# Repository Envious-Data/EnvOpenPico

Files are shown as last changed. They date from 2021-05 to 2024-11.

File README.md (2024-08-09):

# EnvOpenPico
A RP2040 Based family of MCU boards

### Intentions and Info
The intentions of this project were mainly to learn about MCU design and also to make a rpi pico like device using a RP2040 that has some improvements or changes that you'd find useful, so far Ive changed the type-c port and added a reset button as well as replaced the buck boost IC with a linear regulator which doesnt generate the same switching noise which makes it good for audio.

Ive retained the USB TP pads and also TP6 which is bootsel in their original positions.
a couple of the GPIOs cant retain their original function since Im not using a RT6150B-33GQW so GPIO23 has an optional mosfet for a default on LED instead of controlling the mode for the buck-boost IC.

Ive also got nothing connected on GPIO29 where as the pico has a mosfet to prevent leakage current, im not sure what the use of this GPIO is but if its a wanted feature I can try to add it back.

Update: 09th Aug 2024 - Raspberry pi has released the RP235XA and RP235XB, I have started work on making variants of the main Pico board to fit the RP2350 and RP2354.

### Permissions
You have my permission to fork and learn from this design for your own projects including if you wish to sell those on as a product. 

### Important!!
I have only had the EnvOpenPico made so the other variants like the PicoLipo and the EliteMicro2040 I cant fully confirm if the design works but since its all derived from the main project I should hope it all works as intended.

### Notes
- You should be able to order these and have them entirely assembled by other PCBA suppliers if they have stock of all the parts, ive made sure to label everything in the schematic properly.
- Please ensure you pick a compatible flash chip, you may need to modify the connections to the flash chip, its setup for Winbond W25QxxJVxxx.

### Other
If you want to see pictures of the main PCB you can check out the _photos folder

PCBway kindly sponsored a batch of PCBs which you can see pictures of inside the _photos folder.
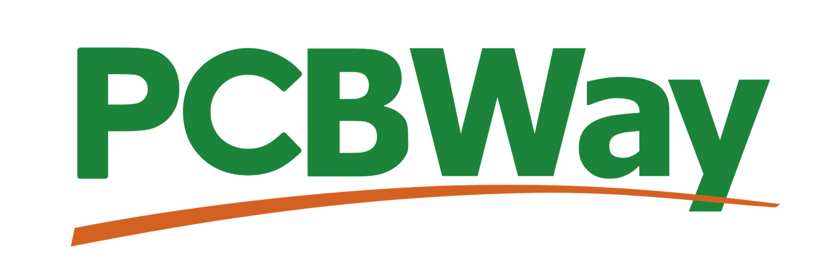
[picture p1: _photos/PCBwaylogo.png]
pcbway logo

http://pcbway.com

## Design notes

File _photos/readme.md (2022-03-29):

PCBWAY Logo

PCBWAY kindly provided some PCBs and components for me, I was also quite impressed at the quality of the PCBs, the castellations are especially good.

https://www.pcbway.com/

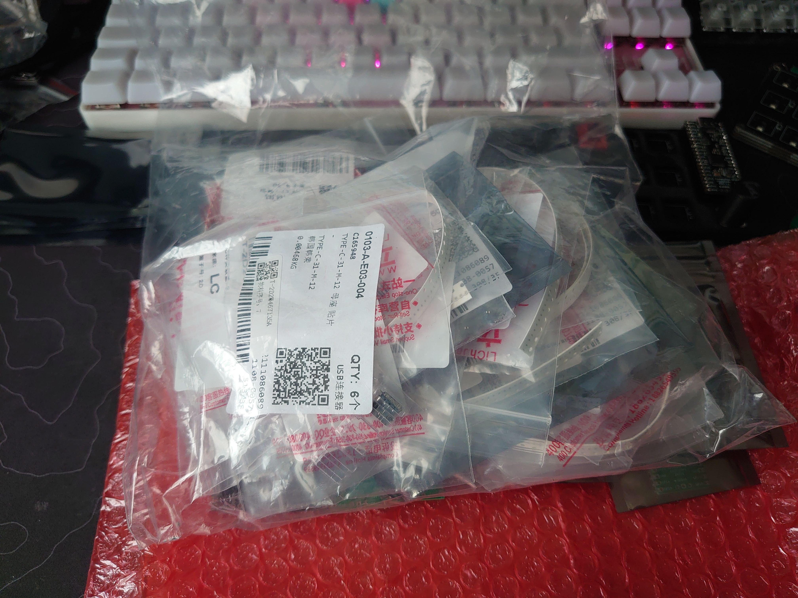
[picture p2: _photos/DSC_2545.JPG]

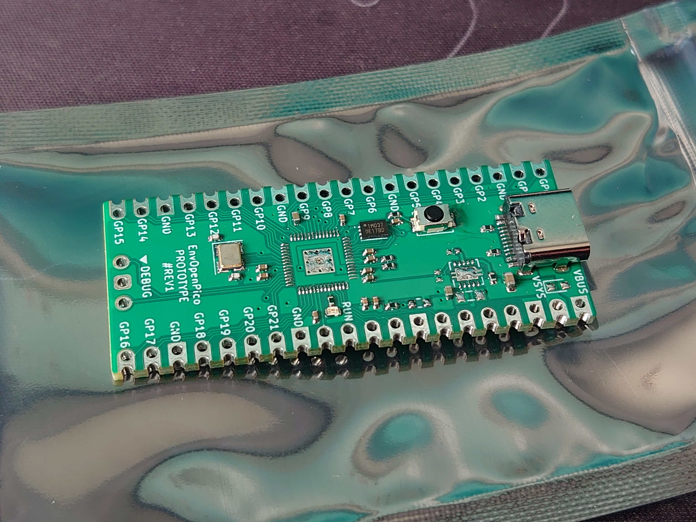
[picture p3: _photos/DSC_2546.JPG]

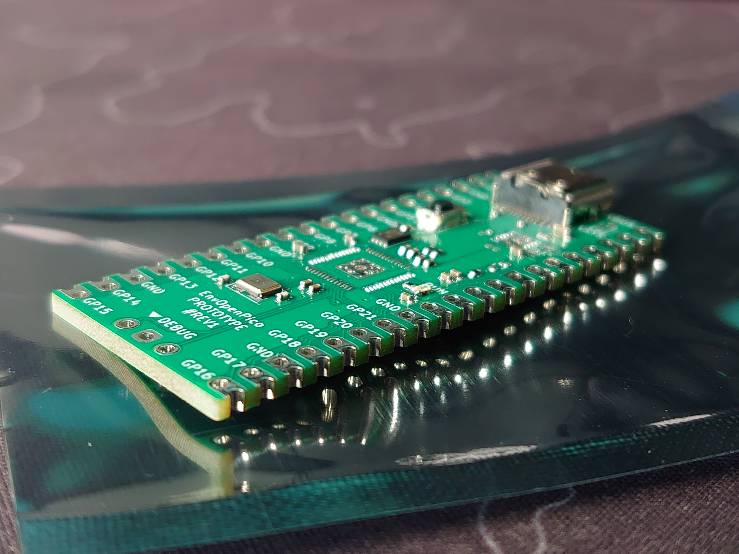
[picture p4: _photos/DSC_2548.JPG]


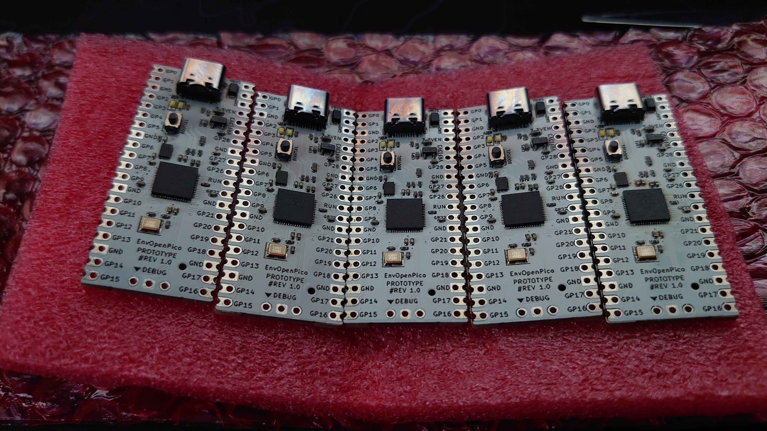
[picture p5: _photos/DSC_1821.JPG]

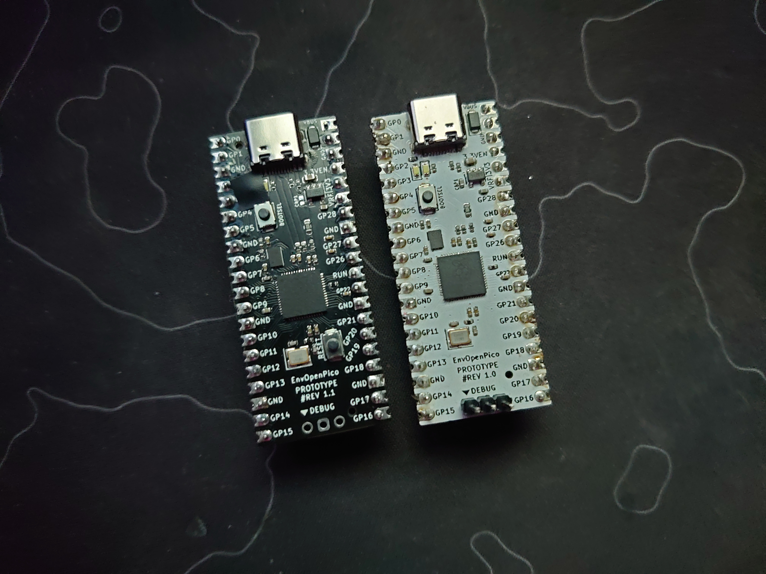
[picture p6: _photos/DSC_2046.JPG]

More PCBs

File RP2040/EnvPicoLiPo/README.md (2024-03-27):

# EnvOpenPico
A Raspberry Pi Pico Clone which also uses the RP2040.

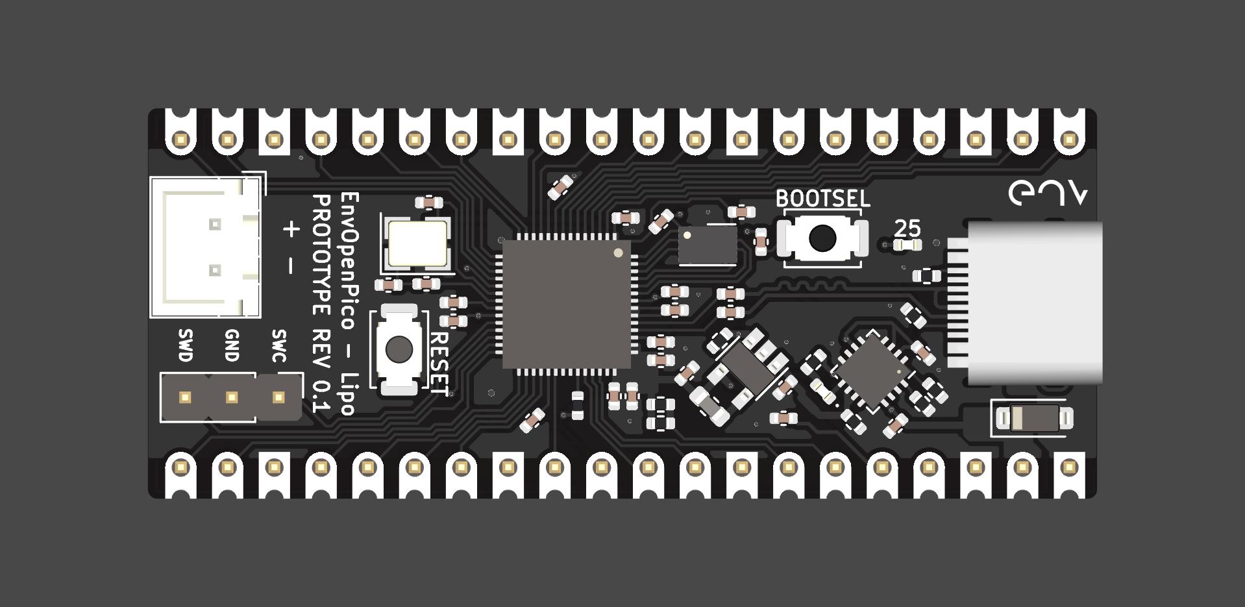
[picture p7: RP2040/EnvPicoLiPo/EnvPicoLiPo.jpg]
Board image


### Info
A pi pico clone with a battery charge and protect IC.

originally this was going to be a version that contains a battery charge IC and a ESP32 wireless slave but I feel like its a bad idea to combine things Ive not worked on before so I scaled back the project to have just a battery PMIC.

### problems
I must point out that alike most things on my github im learning as I go so some pointers on doing things correctly would be apreciated.

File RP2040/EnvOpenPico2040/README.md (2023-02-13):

# EnvOpenPico
A Raspberry Pi Pico Clone which also uses the RP2040.

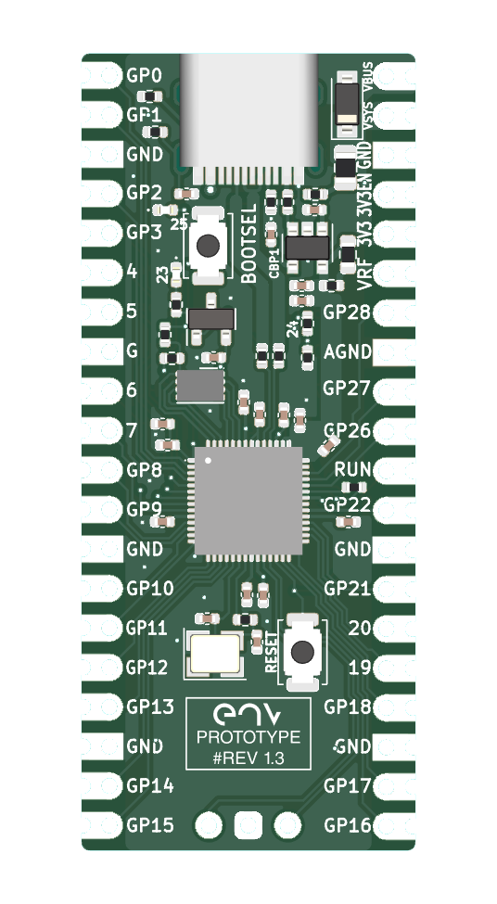
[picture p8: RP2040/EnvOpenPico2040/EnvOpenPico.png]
Board image


### Info
This board is meant to be a mostly drop in replacement for the pico plus and minus some features.

### some notes
I dont update the readme very often so some info here may end up outdated at some point

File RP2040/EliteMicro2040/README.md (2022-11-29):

# EnvOpenPico
A Raspberry Pi RP2040 based board in the shape of an Elite-C.

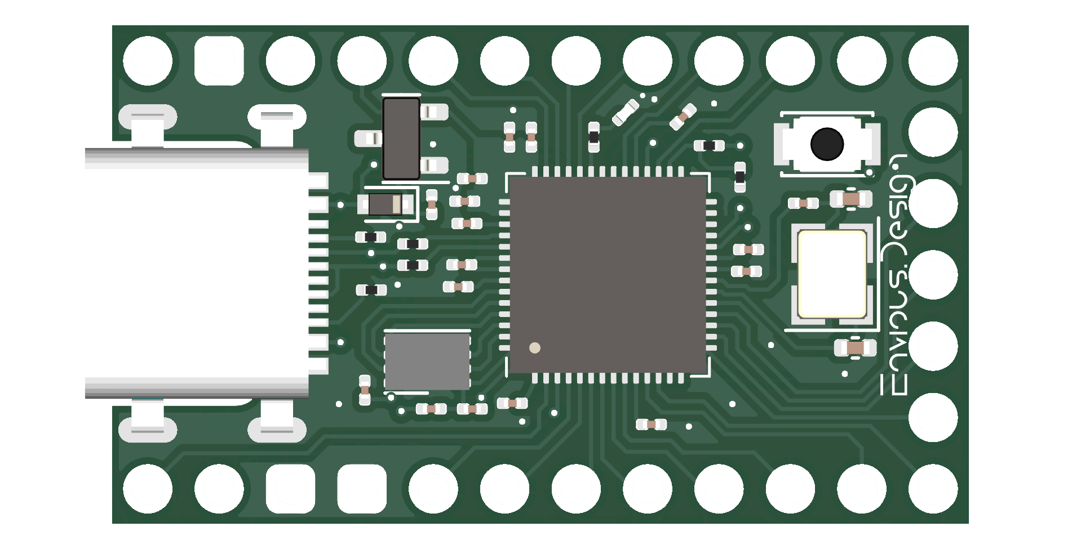
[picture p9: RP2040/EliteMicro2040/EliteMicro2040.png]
Board image


### Info
This board is about 2.5mm shorter than an Elite-C and uses a mid-mount USB C port.

### some notes
I dont update the readme very often so some info here may end up outdated at some point.

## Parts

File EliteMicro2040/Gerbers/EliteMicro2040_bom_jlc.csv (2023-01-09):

Comment | Designator | Footprint | LCSC Part #
1uf 0201 | C1,C3,C4,C10 | C_0201_0603Metric | no_part_number
22pF 0402 | C2 | C_0402_1005Metric | no_part_number
100nf 0201 | C5,C6,C7,C8,C11,C13,C14,C15,C16,C18 | C_0201_0603Metric | no_part_number
22pf 0402 | C19 | C_0402_1005Metric | no_part_number
SOD-523 General | D1 | D_SOD-523 | no_part_number
W25Q16JVUXIQ | FLASH1 | SON-8-1EP_3x2mm_P0.5mm_EP1.4x1.6mm | no_part_number
LED 0201 | GPIO25_LED1 | LED_0201_0603Metric | no_part_number
1K 0201 | GPIO25_RESISTOR1 | R_0201_0603Metric | no_part_number
Button | J1,J2 | SW_SPST_CK_KXT3 | no_part_number
1K 0201 | R1,R7 | C_0201_0603Metric | no_part_number
10K 0201 | R2 | C_0201_0603Metric | no_part_number
27r 0201 | R3,R4 | R_0201_0603Metric | no_part_number
5.1K 0201 | R5,R6 | R_0201_0603Metric | no_part_number
5.6k 0201 | R101 | R_0201_0603Metric | no_part_number
10k 0201 | R102 | R_0201_0603Metric | no_part_number
TestPoint | TP1,TP2,TP101,TP103 | CustomTestPoint | no_part_number
ZL6201A33S3 | U1 | SOT-23 | no_part_number
Elite-C | U2 | Elite-C | no_part_number
RP2040 | U3 | RP2040-QFN-56 | C2040
TYPE-C-31-M-14 | USB1 | USB_C_TYPE-C-31-M-14 | C223907
3225-4P | Y1 | Crystal_SMD_3225-4Pin_3.2x2.5mm | no_part_number

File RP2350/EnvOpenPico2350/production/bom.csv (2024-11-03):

Designator | Footprint | Quantity | Value | LCSC Part #
C1, C17, C4, CBP1 | 0402 | 4 | 10uf 0402
C10, C11, C12, C13, C14, C15, C16, C18, C8 | 0402 | 9 | 100nF 0402
C101 | 0402 | 1 | 0.1uf 0402
C19, C2 | 0402 | 2 | 22pf 0402
C3, C6, C7, C9 | 0402 | 4 | 4.7uF 0402
C5 | 0402 | 1 | 100nf 0402
D1 | D_SOD-123 | 1 | 1N5917W
F1 | 0805 | 1 | 0805L050WR
FB1 | 0402 | 1 | FerriteBead 0402
FLASH1 | Winbond_USON-8-1EP_3x2mm_P0.5mm_EP0.2x1.6mm | 1 | W25Q16JVUXIQ
GP23_LED1 | 0402 | 1 | GP23 LED_0402
GPIO24_RESISTOR1, R1, R11 | 0402 | 3 | 1K 0402
GPIO25_LED1 | 0402 | 1 | LED_0402
GPIO25_RESISTOR1 | 0402 | 1 | 470 0402
J1 | USB_C_Receptacle_HRO_TYPE-C-31-M-12 | 1 | USB_C_Receptacle_USB2.0
J2 | SW_Push_SPST_NO_Alps_SKRK | 1 | TSA343G00-250J2
J3, J4 | PinHeader_1x20_P2.54mm_Vertical | 2 | 2.54mm header 01x20
J5 | PinHeader_1x03_P2.54mm_Vertical | 1 | Conn_01x03_Male
L1 | 0805 | 1 | 3.3uH 0805
NT1 | NetTie-2_SMD_Pad0.5mm | 1 | NetTie_2
Q1 | SOT-23 | 1 | SI2301B
R101 | 0402 | 1 | 5.6K 0402
R102 | 0402 | 1 | 220 0402
R103 | 0402 | 1 | 10K 0402
R2 | 0402 | 1 | 10K 0402
R3, R4 | 0402 | 2 | 27ohm 0402
R5, R6 | 0402 | 2 | 5.1K 0402
R7 | 0402 | 1 | 100K 0402
R8 | 0402 | 1 | 33ohm 0402
RSW1 | SW_Push_SPST_NO_Alps_SKRK | 1 | TSA343G00-250J2
TP1, TP2, TP3 | CustomTestPoint | 3 | TestPoint
U1 | SOT-23-5 | 1 | SOT-23-5 5.5V 3.3V 500mA
U3 | QFN-60-1EP_7x7mm_P0.4mm_EP3.4x3.4mm_ThermalVias | 1 | RP2350A
Y1 | Crystal_SMD_3225-4Pin_3.2x2.5mm | 1 | 3225_4P 12MHz

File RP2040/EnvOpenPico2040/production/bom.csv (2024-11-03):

Designator | Footprint | Quantity | Value | LCSC Part #
C1, C17, C4, CBP1 | 0402 | 4 | 10uf 0402
C10, C102 | 0402 | 2 | 2.2uF 0402
C101 | 0402 | 1 | 0.1uf 0402
C11, C13, C14, C15, C16, C18, C5, C6, C7, C8 | 0402 | 10 | 100nf 0402
C19, C2 | 0402 | 2 | 22pf 0402
C3 | 0402 | 1 | 1uf 0402
D1 | D_SOD-123 | 1 | 1N5817W
F1 | 0805 | 1 | 0805L050WR
FB1 | 0402 | 1 | FerriteBead 0402
FLASH1 | Winbond_USON-8-1EP_3x2mm_P0.5mm_EP0.2x1.6mm | 1 | W25Q16JVUXIQ
GP23_LED1 | 0402 | 1 | GP23 LED_0402
GPIO24_RESISTOR1, R1, R11 | 0402 | 3 | 1K 0402
GPIO25_LED1 | 0402 | 1 | LED_0402
GPIO25_RESISTOR1 | 0402 | 1 | 470 0402
J1 | USB_C_Receptacle_HRO_TYPE-C-31-M-12 | 1 | USB_C_Receptacle_USB2.0
J2 | SW_Push_SPST_NO_Alps_SKRK | 1 | Button
J3, J4 | PinHeader_1x20_P2.54mm_Vertical | 2 | 2.54mm header 01x20
J5 | PinHeader_1x03_P2.54mm_Vertical | 1 | Conn_01x03_Male
NT1 | NetTie-2_SMD_Pad0.5mm | 1 | NetTie_2
Q1 | SOT-23 | 1 | SI2301B
R10 | 0402 | 1 | 1 0402
R101 | 0402 | 1 | 5.6K 0402
R102 | 0402 | 1 | 220 0402
R103 | 0402 | 1 | 10K 0402
R2 | 0402 | 1 | 10K 0402
R3, R4 | 0402 | 2 | 27r 0402 resistor
R5, R6 | 0402 | 2 | 5.1K 0402
R7 | 0402 | 1 | 100K 0402
R9 | 0603 | 1 | 200 0603
RSW1 | SW_Push_SPST_NO_Alps_SKRK | 1 | TSA343G00-250J2
TP1, TP2, TP3 | CustomTestPoint | 3 | TestPoint
U1 | SOT-23-5 | 1 | SOT-23-5 5.5V 3.3V 500mA
U3 | RP2040-QFN-56 | 1 | RP2040 | C2040
Y1 | Crystal_SMD_3225-4Pin_3.2x2.5mm | 1 | 3225_4P 12MHz

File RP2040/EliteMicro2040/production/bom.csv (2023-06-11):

Designator | Footprint | Quantity | Value | LCSC Part #
C1, C10, C3, C4 | 0402 | 4 | 1uf 0402
C11, C13, C14, C15, C18, C5, C6, C7, C8 | 0402 | 9 | 100nf 0402
C19, C2 | 0402 | 2 | 22pf 0402
D1 | D_SOD-523 | 1 | SOD-523 General
FLASH1 | SON-8-1EP_3x2mm_P0.5mm_EP1.4x1.6mm | 1 | W25Q16JVUXIQ
GPIO25_LED1 | 0402 | 1 | LED 0402
GPIO25_RESISTOR1, R1, R7 | 0402 | 3 | 1K 0402
J1, J2 | SW_SPST_CK_KXT3 | 2 | Button
R101 | 0402 | 1 | 5.6k 0402
R102, R2 | 0402 | 2 | 10k 0402
R3, R4 | 0402 | 2 | 27r 0402
R5, R6 | 0402 | 2 | 5.1K 0402
TP1, TP101, TP103, TP2 | CustomTestPoint | 4 | TestPoint
U1 | SOT-23 | 1 | ZL6201A33S3
U2 | Elite-C | 1 | Elite-C
U3 | RP2040-QFN-56 | 1 | RP2040 | C2040
USB2 | HRO-TYPE-C-31-M-12 | 1 | HRO-TYPE-C-31-M-12
Y1 | Crystal_SMD_3225-4Pin_3.2x2.5mm | 1 | 3225-4P 12MHz

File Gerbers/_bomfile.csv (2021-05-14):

Comment | Designator | Footprint | LCSC
10u | C1,C4,C17 | Capacitor_SMD:C_0402_1005Metric
1u | C3,C10 | Capacitor_SMD:C_0402_1005Metric
15p | C2 | Capacitor_SMD:C_0402_1005Metric
100n | C5,C6,C7,C8,C11,C13,C14,C15 | Capacitor_SMD:C_0402_1005Metric
0603 Diode 1N58 | D2 | Diode_SMD:D_0603_1608Metri
LED 0402 YELLOW | D3 | LED_SMD:LED_0402_1005Metric
MountingHole | H1,H2,H3,H4 | MountingHole:MountingHole_2.2mm_M2
B3U-1000P | J2 | Button_Switch_SMD:SW_SPST_B3U-1000P
Conn_02x18_Odd_Even | J3,J4 | Connector_PinHeader_2.54mm:PinHeader_1x20_P2.54mm_Vertical
Conn_01x03_Male | J5 | Connector_PinHeader_2.54mm:PinHeader_1x03_P2.54mm_Vertical
1k | R1 | Capacitor_SMD:C_0402_1005Metric
DNF | R2 | Capacitor_SMD:C_0402_1005Metric
27 0402 Resistor | R3,R4 | Capacitor_SMD:C_0402_1005Metric
5.1K | R5,R6 | Resistor_SMD:R_0402_1005Metric
100K | R7 | Resistor_SMD:R_0402_1005Metric
470 | R8 | Resistor_SMD:R_0402_1005Metric
SPX3819M5-L-3-3 | U1 | Package_TO_SOT_SMD:SOT-23-5
W25Q128JVPIQ | U2
RP2040 | U3 | RP2040_minimal:RP2040-QFN-56
XO 32 12Mhz | X1 | Crystal:Crystal_SMD_SeikoEpson_TSX3225-4Pin_3.2x2.5mm
TYPE-C-31-M-12 | e1 | Connector_USB:USB_C_Receptacle_HRO_TYPE-C-31-M-12

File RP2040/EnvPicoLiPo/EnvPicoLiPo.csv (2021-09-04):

Source: | C:\Users\Envy\Documents\GitHub\EnvOpenPico\EnvPicoLiPo\EnvPicoLiPo.kicad_sch
Date: | 23/08/2021 20:36:56
Tool: | Eeschema (5.99.0-11630-gc5e195bdff)
Generator: | C:\Program Files\KiCad\5.99\bin\scripting\plugins/bom_csv_grouped_by_value.py
Component Count: | 52
Individual Components:
Item | Qty | Reference(s) | Value | LibPart | Footprint | Datasheet | MANUFACTURER
 |  | BT1 | Li-Po Battery | Device:Battery_Cell | Connector_JST:JST_PH_B2B-PH-SM4-TB_1x02-1MP_P2.00mm_Vertical | ~
 |  | C1 | 10uf 0603 6.3V | Device:C | Capacitor_SMD:C_0603_1608Metric | ~
 |  | C2 | 15pf 0402 | Device:C | Capacitor_SMD:C_0402_1005Metric | ~
 |  | C3 | 1uf 0402 | Device:C | Capacitor_SMD:C_0402_1005Metric | ~
 |  | C5 | 100nf 0402 | Device:C | Capacitor_SMD:C_0402_1005Metric | ~
 |  | C6 | 100nf 0402 | Device:C | Capacitor_SMD:C_0402_1005Metric | ~
 |  | C7 | 100nf 0402 | Device:C | Capacitor_SMD:C_0402_1005Metric | ~
 |  | C8 | 100nf 0402 | Device:C | Capacitor_SMD:C_0402_1005Metric | ~
 |  | C9 | 10uf 0402 | Device:C | Capacitor_SMD:C_0402_1005Metric | ~
 |  | C10 | 1uf 0402 | Device:C | Capacitor_SMD:C_0402_1005Metric | ~
 |  | C11 | 100nf 0402 | Device:C | Capacitor_SMD:C_0402_1005Metric | ~
 |  | C13 | 100nf 0402 | Device:C | Capacitor_SMD:C_0402_1005Metric | ~
 |  | C14 | 100nf 0402 | Device:C | Capacitor_SMD:C_0402_1005Metric | ~
 |  | C15 | 100nf 0402 | Device:C | Capacitor_SMD:C_0402_1005Metric | ~
 |  | C16 | 100nf 0402 | Device:C | Capacitor_SMD:C_0402_1005Metric | ~
 |  | C17 | 10uf 0402 | Device:C | Capacitor_SMD:C_0402_1005Metric | ~
 |  | C18 | 100nf 0402 | Device:C | Capacitor_SMD:C_0402_1005Metric | ~
 |  | C19 | 0402 1uF | Device:C_Small | Capacitor_SMD:C_0402_1005Metric | ~
 |  | C20 | 0402 10uF | Device:C_Small | Resistor_SMD:R_0402_1005Metric | ~
 |  | C21 | 4.7uf 0402 | Device:C_Small | Capacitor_SMD:C_0402_1005Metric | ~
 |  | D2 | 0402 led | Device:LED_Small | LED_SMD:LED_0402_1005Metric | ~
 |  | D3 | LED 0402 YELLOW | Device:LED | LED_SMD:LED_0402_1005Metric | ~
 |  | D4 | 1n4002 0603 | Device:D_Schottky | Diode_SMD:D_0603_1608Metric | ~
 |  | e1 | TYPE-C-31-M-12 | Type-C:HRO-TYPE-C-31-M-12 | HRO-TYPE-C31-M-12:HRO-TYPE-C-31-M-12
 |  | FLASH1 | W25Q16 | W25Q256JVEIQ_TR:W25Q256JVEIQ_TR | Package_SON:SON-8-1EP_3x2mm_P0.5mm_EP1.4x1.6mm |  | Winbond Electronics Corp.
 |  | H1 | MountingHole | Mechanical:MountingHole | MountingHole:MountingHole_2.2mm_M2 | ~
 |  | H2 | MountingHole | Mechanical:MountingHole | MountingHole:MountingHole_2.2mm_M2 | ~
 |  | H3 | MountingHole | Mechanical:MountingHole | MountingHole:MountingHole_2.2mm_M2 | ~
 |  | H4 | MountingHole | Mechanical:MountingHole | MountingHole:MountingHole_2.2mm_M2 | ~
 |  | J2 | SKRKAEE020 | Switch:SW_Push | Button_Switch_SMD:SW_Push_SPST_NO_Alps_SKRK | ~
 |  | J3 | 2.54mm header 01x20 | Connector_Generic:Conn_01x20 | Connector_PinHeader_2.54mm:PinHeader_1x20_P2.54mm_Vertical | ~
 |  | J4 | 2.54mm header 01x20 | Connector_Generic:Conn_01x20 | Connector_PinHeader_2.54mm:PinHeader_1x20_P2.54mm_Vertical | ~
 |  | J5 | Conn_01x03_Male | Connector_Generic:Conn_01x03 | Connector_PinHeader_2.54mm:PinHeader_1x03_P2.54mm_Vertical | ~
 |  | L1 | INDUCTOR 2.2uH 0805 | pspice:INDUCTOR | Inductor_SMD:L_0805_2012Metric | ~
 |  | NT1 | Net-Tie_2 | Device:Net-Tie_2 | NetTie:NetTie-2_SMD_Pad0.5mm | ~
 |  | R1 | 1k 0402 Resistor | Device:R | Capacitor_SMD:C_0402_1005Metric | ~
 |  | R2 | DNF | Device:R | Capacitor_SMD:C_0402_1005Metric | ~
 |  | R3 | 27Ohms 0402 Resistor | Device:R | Capacitor_SMD:C_0402_1005Metric | ~
 |  | R4 | 27Ohms 0402 Resistor | Device:R | Capacitor_SMD:C_0402_1005Metric | ~
 |  | R5 | 5.1K | Device:R_Small | Resistor_SMD:R_0402_1005Metric | ~
 |  | R6 | 5.1K | Device:R_Small | Resistor_SMD:R_0402_1005Metric | ~
 |  | R7 | 100k 0402 | Device:R | Resistor_SMD:R_0402_1005Metric | ~
 |  | R8 | 470 ohm resistor | Device:R | Resistor_SMD:R_0402_1005Metric | ~
 |  | R9 | 200ohm 0603 | Device:R_Small | Resistor_SMD:R_0603_1608Metric | ~
 |  | R10 | 1Ohm 0402 | Device:R_Small | Resistor_SMD:R_0402_1005Metric | ~
 |  | R11 | 10K 0402 | Device:R_Small | Resistor_SMD:R_0402_1005Metric | ~
 |  | R12 | 10K 0402 | Device:R_Small | Resistor_SMD:R_0402_1005Metric | ~
 |  | R14 | 2.2K 0402 | Device:R_Small | Resistor_SMD:R_0402_1005Metric | ~
 |  | U1 | LM3671MF 3.3 | Regulator_Switching:LM3670MF | Package_TO_SOT_SMD:TSOT-23-5 | http://www.ti.com/lit/ds/symlink/lm3670.pdf
 |  | U2 | BQ24072RGT | Battery_Management:BQ24072RGT | Package_DFN_QFN:VQFN-16-1EP_3x3mm_P0.5mm_EP1.6x1.6mm | http://www.ti.com/lit/ds/symlink/bq24072.pdf
 |  | U3 | RP2040 | MCU_RaspberryPi_RP2040:RP2040 | RP2040_minimal:RP2040-QFN-56
 |  | X1 | XO 32 12Mhz 3225 seiko | Oscillator:XO32 | Crystal:Crystal_SMD_SeikoEpson_TSX3225-4Pin_3.2x2.5mm | http://cdn-reichelt.de/documents/datenblatt/B400/XO32.pdf
Collated Components:
Item | Qty | Reference(s) | Value | LibPart | Footprint | Datasheet | MANUFACTURER
1 | 1 | BT1 | Li-Po Battery | Device:Battery_Cell | Connector_JST:JST_PH_B2B-PH-SM4-TB_1x02-1MP_P2.00mm_Vertical | ~
2 | 1 | C1 | 10uf 0603 6.3V | Device:C | Capacitor_SMD:C_0603_1608Metric | ~
3 | 1 | C2 | 15pf 0402 | Device:C | Capacitor_SMD:C_0402_1005Metric | ~
4 | 2 | C3, C10 | 1uf 0402 | Device:C | Capacitor_SMD:C_0402_1005Metric | ~
5 | 10 | C5, C6, C7, C8, C11, C13, C14, C15, C16, C18 | 100nf 0402 | Device:C | Capacitor_SMD:C_0402_1005Metric | ~
6 | 2 | C9, C17 | 10uf 0402 | Device:C | Capacitor_SMD:C_0402_1005Metric | ~
7 | 1 | C19 | 0402 1uF | Device:C_Small | Capacitor_SMD:C_0402_1005Metric | ~
8 | 1 | C20 | 0402 10uF | Device:C_Small | Resistor_SMD:R_0402_1005Metric | ~
9 | 1 | C21 | 4.7uf 0402 | Device:C_Small | Capacitor_SMD:C_0402_1005Metric | ~
10 | 1 | D2 | 0402 led | Device:LED_Small | LED_SMD:LED_0402_1005Metric | ~
11 | 1 | D3 | LED 0402 YELLOW | Device:LED | LED_SMD:LED_0402_1005Metric | ~
12 | 1 | D4 | 1n4002 0603 | Device:D_Schottky | Diode_SMD:D_0603_1608Metric | ~
13 | 1 | e1 | TYPE-C-31-M-12 | Type-C:HRO-TYPE-C-31-M-12 | HRO-TYPE-C31-M-12:HRO-TYPE-C-31-M-12
14 | 1 | FLASH1 | W25Q16 | W25Q256JVEIQ_TR:W25Q256JVEIQ_TR | Package_SON:SON-8-1EP_3x2mm_P0.5mm_EP1.4x1.6mm |  | Winbond Electronics Corp.
15 | 4 | H1, H2, H3, H4 | MountingHole | Mechanical:MountingHole | MountingHole:MountingHole_2.2mm_M2 | ~
16 | 1 | J2 | SKRKAEE020 | Switch:SW_Push | Button_Switch_SMD:SW_Push_SPST_NO_Alps_SKRK | ~
17 | 2 | J3, J4 | 2.54mm header 01x20 | Connector_Generic:Conn_01x20 | Connector_PinHeader_2.54mm:PinHeader_1x20_P2.54mm_Vertical | ~
18 | 1 | J5 | Conn_01x03_Male | Connector_Generic:Conn_01x03 | Connector_PinHeader_2.54mm:PinHeader_1x03_P2.54mm_Vertical | ~
19 | 1 | L1 | INDUCTOR 2.2uH 0805 | pspice:INDUCTOR | Inductor_SMD:L_0805_2012Metric | ~
20 | 1 | NT1 | Net-Tie_2 | Device:Net-Tie_2 | NetTie:NetTie-2_SMD_Pad0.5mm | ~
21 | 1 | R1 | 1k 0402 Resistor | Device:R | Capacitor_SMD:C_0402_1005Metric | ~
22 | 1 | R2 | DNF | Device:R | Capacitor_SMD:C_0402_1005Metric | ~
23 | 1 | R3 | 27Ohms 0402 Resistor | Device:R | Capacitor_SMD:C_0402_1005Metric | ~
24 | 1 | R4 | 27Ohms 0402 Resistor | Device:R | Capacitor_SMD:C_0402_1005Metric | ~
25 | 2 | R5, R6 | 5.1K | Device:R_Small | Resistor_SMD:R_0402_1005Metric | ~
26 | 1 | R7 | 100k 0402 | Device:R | Resistor_SMD:R_0402_1005Metric | ~
27 | 1 | R8 | 470 ohm resistor | Device:R | Resistor_SMD:R_0402_1005Metric | ~
28 | 1 | R9 | 200ohm 0603 | Device:R_Small | Resistor_SMD:R_0603_1608Metric | ~
29 | 1 | R10 | 1Ohm 0402 | Device:R_Small | Resistor_SMD:R_0402_1005Metric | ~
30 | 2 | R11, R12 | 10K 0402 | Device:R_Small | Resistor_SMD:R_0402_1005Metric | ~
31 | 1 | R14 | 2.2K 0402 | Device:R_Small | Resistor_SMD:R_0402_1005Metric | ~
32 | 1 | U1 | LM3671MF 3.3 | Regulator_Switching:LM3670MF | Package_TO_SOT_SMD:TSOT-23-5 | http://www.ti.com/lit/ds/symlink/lm3670.pdf
33 | 1 | U2 | BQ24072RGT | Battery_Management:BQ24072RGT | Package_DFN_QFN:VQFN-16-1EP_3x3mm_P0.5mm_EP1.6x1.6mm | http://www.ti.com/lit/ds/symlink/bq24072.pdf
34 | 1 | U3 | RP2040 | MCU_RaspberryPi_RP2040:RP2040 | RP2040_minimal:RP2040-QFN-56
35 | 1 | X1 | XO 32 12Mhz 3225 seiko | Oscillator:XO32 | Crystal:Crystal_SMD_SeikoEpson_TSX3225-4Pin_3.2x2.5mm | http://cdn-reichelt.de/documents/datenblatt/B400/XO32.pdf

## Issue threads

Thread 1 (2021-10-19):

Could I reuse your schematics?

goran-mahovlic, 2021-10-19:
Hi, I have some audio project that needs RP2040 as MCU so I am wondering can I just reuse your schematics and start from it?

For my board I would redo complete PCB - but if you want I can also check/order and assemble your PCB, and confirm if everything is working...

goran-mahovlic, 2021-10-31:
Thank you  for info. Next week we will probably need to order test boards.
Is the Winbond footprint the same?

Envious-Data, 2021-10-31:
Ye the footprint on the board and poinout will fit
- W25Q16FWUXIE
- W25Q16JVUXIM

atleast based on https://www.winbond.com/resource-files/w25q16fw%20revj%2005182017%20sfdp.pdf and https://www.winbond.com/resource-files/w25q16jv spi revf 05092017.pdf

Ive seen some other RP2040 boards use flash chips listed in this repo
https://github.com/adafruit/nvm.toml/tree/e5b149599d14a8841167fe552846ca36925b87a0/flash/winbond

Also JLCPCB does stock W25Q16FWUXIE

goran-mahovlic, 2021-11-03:
Great, I have ordered some W25Q so I will check will it work.

Here is V1.0 - so hopefully most things will work. In next version I will need to move RP2040 and all components as top and bottom parts are separated with printed part that will now have strange hole in the place of MCU.

https://github.com/intergalaktik/SynthoGame

I will close this issue.

goran-mahovlic, 2021-11-12:
It works! At least bottom board - LEDs and sound(DAC and AMP) works!
Now I need to solder top board and connect everything...

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

Closed 2021-11-03.

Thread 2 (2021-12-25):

W25Q16FWUXIE requires 1.65v to 1.95v supply

xyzz, 2021-12-25:
As per the datasheet:
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

It is currently connected to 3.3v I don't think that would work
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

Envious-Data, 2021-12-25:
Ah I should probably change that to W25Q16JVUXIQ since its a placeholder but not listed as such.

Closed 2021-12-27.

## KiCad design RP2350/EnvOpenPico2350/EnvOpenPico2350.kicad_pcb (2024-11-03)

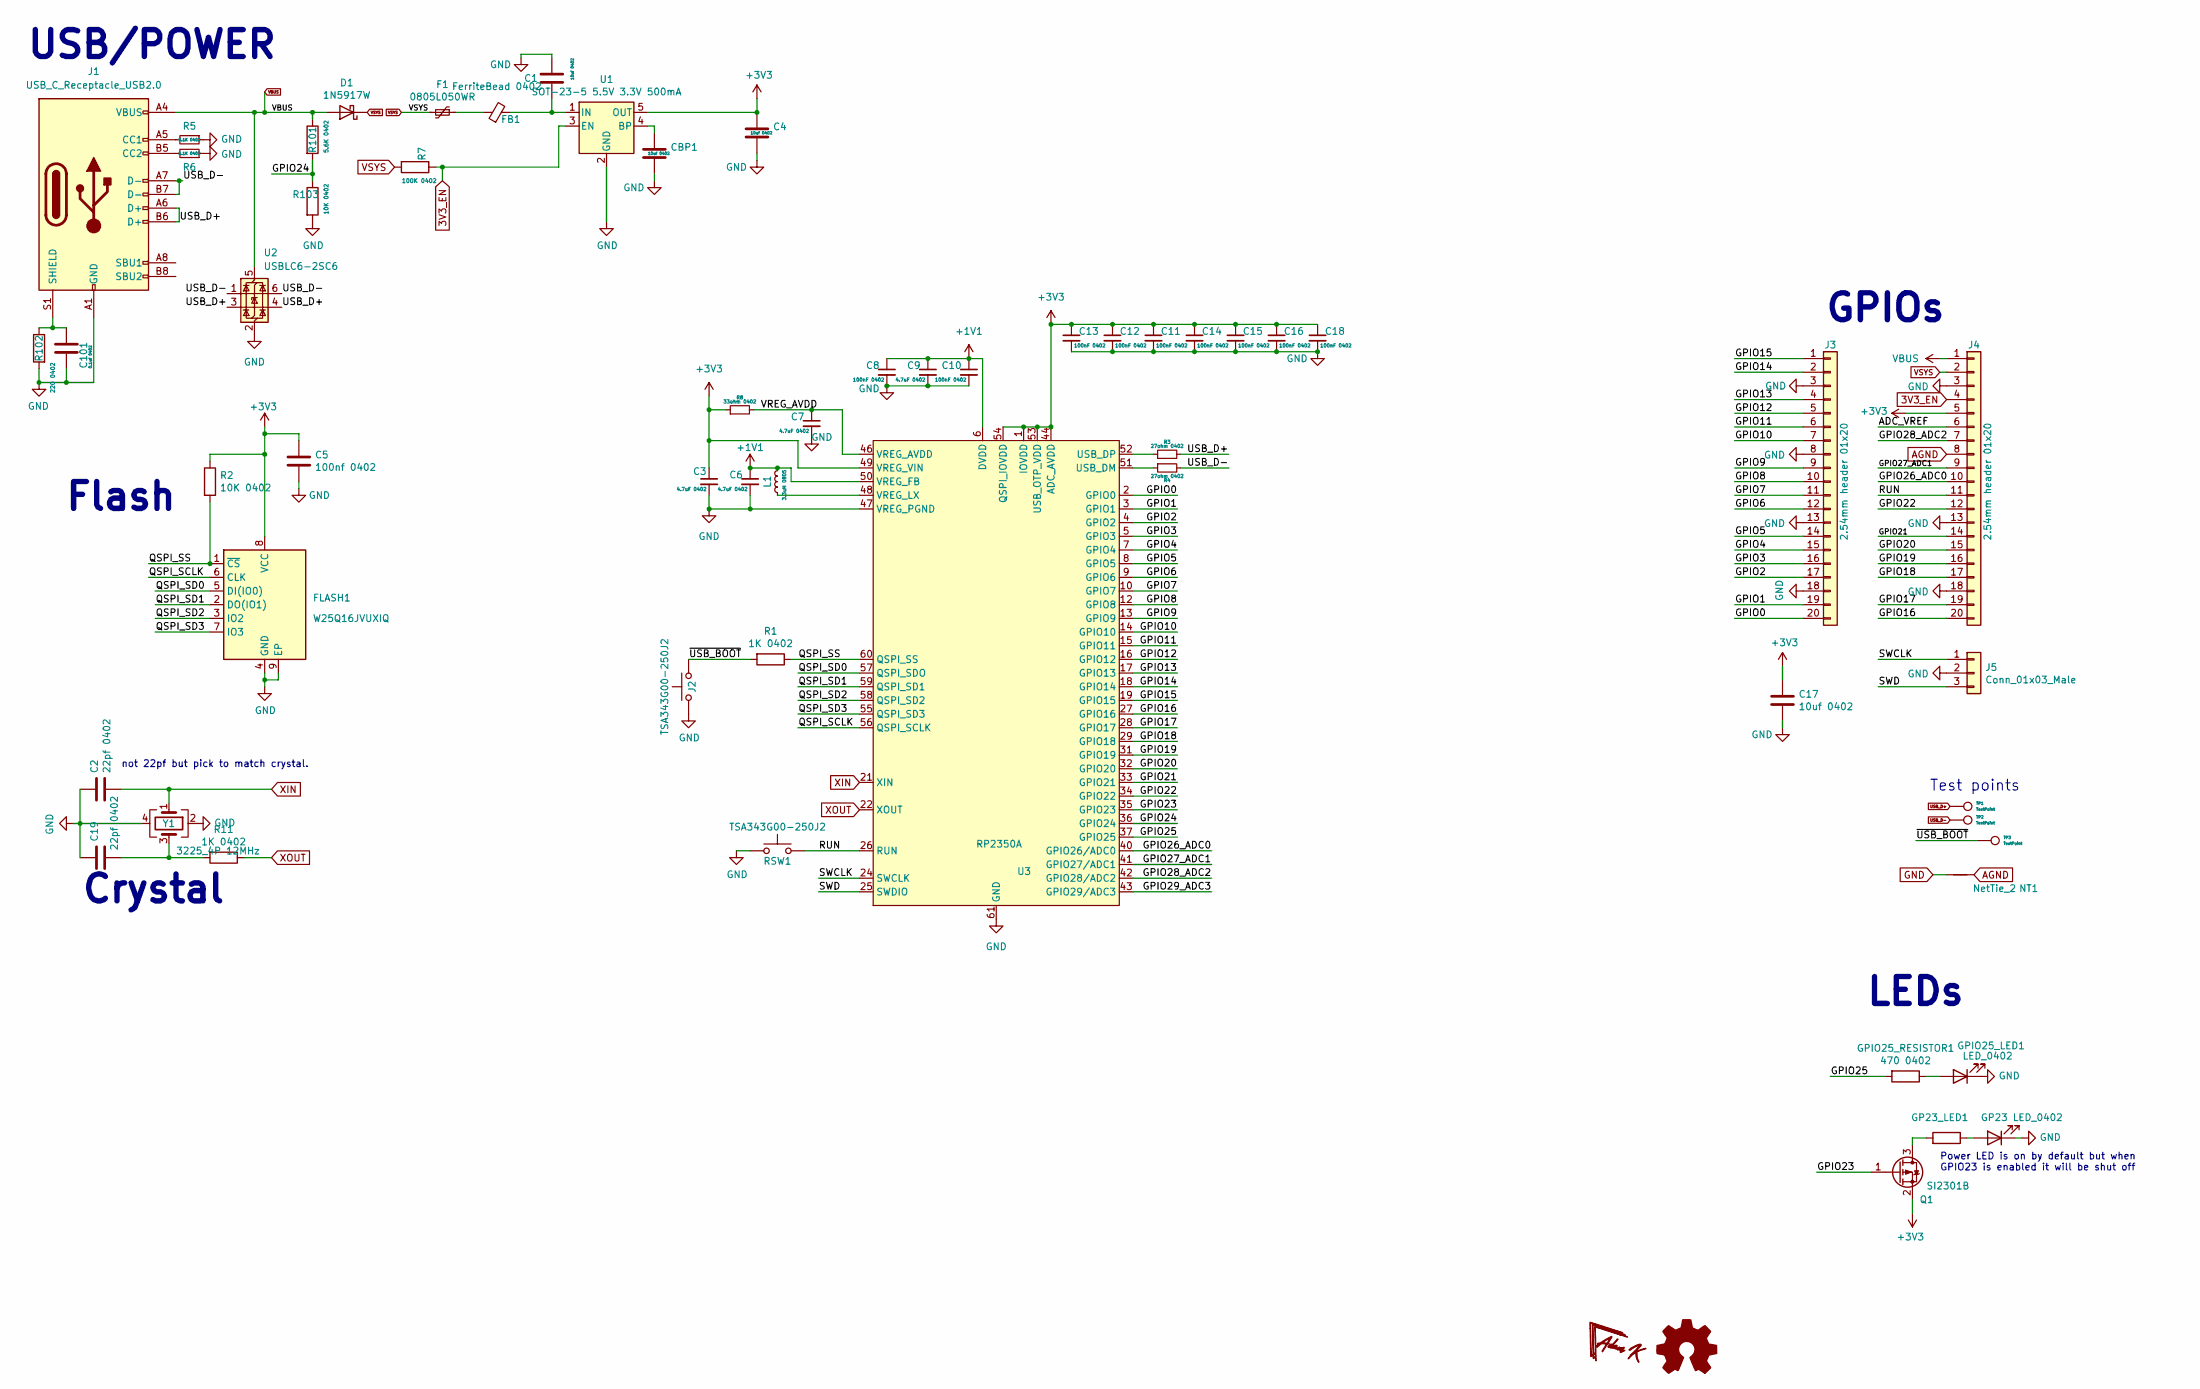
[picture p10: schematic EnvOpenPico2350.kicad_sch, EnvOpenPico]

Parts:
C1, C4, C17: 10uf 0402; C_0402_1005Metric
C2, C19: 22pf 0402; C_0402_1005Metric
C3, C6, C7, C9: 4.7uF 0402; C_0402_1005Metric
C5: 100nf 0402; C_0402_1005Metric
C8, C10, C11, C12, C13, C14, C15, C16, C18: 100nF 0402; C_0402_1005Metric
C101: 0.1uf 0402; C_0402_1005Metric
CBP1: 10uf 0402; C_0402_1005Metric
D1: 1N5917W; D_SOD-123
F1: 0805L050WR; Fuse_0805_2012Metric
FB1: FerriteBead 0402; R_0402_1005Metric
FLASH1: W25Q16JVUXIQ; Winbond_USON-8-1EP_3x2mm_P0.5mm_EP0.2x1.6mm
GP23_LED1: GP23 LED_0402; LED_0402_1005Metric
GPIO24_RESISTOR1: 1K 0402; R_0402_1005Metric
GPIO25_LED1: LED_0402; LED_0402_1005Metric
GPIO25_RESISTOR1: 470 0402; R_0402_1005Metric
J1: USB_C_Receptacle_USB2.0; USB_C_Receptacle_HRO_TYPE-C-31-M-12
J2: TSA343G00-250J2; SW_Push_SPST_NO_Alps_SKRK
J3, J4: 2.54mm header 01x20; PinHeader_1x20_P2.54mm_Vertical
J5: Conn_01x03_Male; PinHeader_1x03_P2.54mm_Vertical
L1: 3.3uH 0805; L_0805_2012Metric
NT1: NetTie_2; NetTie-2_SMD_Pad0.5mm
Q1: SI2301B; SOT-23
R1, R11: 1K 0402; R_0402_1005Metric
R2, R103: 10K 0402; R_0402_1005Metric
R3, R4: 27ohm 0402; R_0402_1005Metric
R5, R6: 5.1K 0402; R_0402_1005Metric
R7: 100K 0402; R_0402_1005Metric
R8: 33ohm 0402; R_0402_1005Metric
R101: 5.6K 0402; R_0402_1005Metric
R102: 220 0402; R_0402_1005Metric
RSW1: TSA343G00-250J2; SW_Push_SPST_NO_Alps_SKRK
TP1, TP2, TP3: TestPoint; CustomTestPoint
U1: SOT-23-5 5.5V 3.3V 500mA; SOT-23-5
U2: USBLC6-2SC6; SOT-23-6
U3: RP2350A; QFN-60-1EP_7x7mm_P0.4mm_EP3.4x3.4mm_ThermalVias
Y1: 3225_4P 12MHz; Crystal_SMD_3225-4Pin_3.2x2.5mm

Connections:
3V3_EN: J4.4, R7.1, U1.3 (EN)
+1V1: C6.1, C8.1, C9.1, C10.1, L1.1, U3.6 (DVDD), U3.23 (DVDD), U3.39 (DVDD), U3.50 (VREG_FB)
+3V3: C3.1, C4.1, C5.1, C11.1, C12.1, C13.1, C14.1, C15.1, C16.1, C17.1, C18.1, FLASH1.8 (VCC), J4.5, Q1.2 (S), R2.1, R8.1, U1.5 (OUT), U3.1 (IOVDD), U3.11 (IOVDD), U3.20 (IOVDD), U3.30 (IOVDD), U3.38 (IOVDD), U3.44 (ADC_AVDD), U3.45 (IOVDD), U3.49 (VREG_VIN), U3.53 (USB_OTP_VDD), U3.54 (QSPI_IOVDD)
/ADC_VREF: J4.6
/GPIO0: J3.20, U3.2 (GPIO0)
/GPIO1: J3.19, U3.3 (GPIO1)
/GPIO2: J3.17, U3.4 (GPIO2)
/GPIO3: J3.16, U3.5 (GPIO3)
/GPIO4: J3.15, U3.7 (GPIO4)
/GPIO5: J3.14, U3.8 (GPIO5)
/GPIO6: J3.12, U3.9 (GPIO6)
/GPIO7: J3.11, U3.10 (GPIO7)
/GPIO8: J3.10, U3.12 (GPIO8)
/GPIO9: J3.9, U3.13 (GPIO9)
/GPIO10: J3.7, U3.14 (GPIO10)
/GPIO11: J3.6, U3.15 (GPIO11)
/GPIO12: J3.5, U3.16 (GPIO12)
/GPIO13: J3.4, U3.17 (GPIO13)
/GPIO14: J3.2, U3.18 (GPIO14)
/GPIO15: J3.1, U3.19 (GPIO15)
/GPIO16: J4.20, U3.27 (GPIO16)
/GPIO17: J4.19, U3.28 (GPIO17)
/GPIO18: J4.17, U3.29 (GPIO18)
/GPIO19: J4.16, U3.31 (GPIO19)
/GPIO20: J4.15, U3.32 (GPIO20)
/GPIO21: J4.14, U3.33 (GPIO21)
/GPIO22: J4.12, U3.34 (GPIO22)
/GPIO23: Q1.1 (G), U3.35 (GPIO23)
/GPIO24: R101.2, R103.1, U3.36 (GPIO24)
/GPIO25: GPIO25_RESISTOR1.2, U3.37 (GPIO25)
/GPIO26_ADC0: J4.10, U3.40 (GPIO26/ADC0)
/GPIO27_ADC1: J4.9, U3.41 (GPIO27/ADC1)
/GPIO28_ADC2: J4.7, U3.42 (GPIO28/ADC2)
/GPIO29_ADC3: U3.43 (GPIO29/ADC3)
/QSPI_SCLK: FLASH1.6 (CLK), U3.56 (QSPI_SCLK)
/QSPI_SD0: FLASH1.5 (DI(IO0)), U3.57 (QSPI_SDO)
/QSPI_SD1: FLASH1.2 (DO(IO1)), U3.59 (QSPI_SD1)
/QSPI_SD2: FLASH1.3 (IO2), U3.58 (QSPI_SD2)
/QSPI_SD3: FLASH1.7 (IO3), U3.55 (QSPI_SD3)
/QSPI_SS: FLASH1.1 (~CS), R1.1, R2.2, U3.60 (QSPI_SS)
/RUN: J4.11, RSW1.2, U3.26 (RUN)
/SWCLK: J5.1, U3.24 (SWCLK)
/SWD: J5.3, U3.25 (SWDIO)
/VREG_AVDD: C7.1, R8.2, U3.46 (VREG_AVDD)
/~USB_BOOT: J2.2, R1.2, TP3.1
AGND: J4.8, NT1.2
GND: C1.2, C2.1, C3.2, C4.2, C5.2, C6.2, C7.2, C8.2, C9.2, C10.2, C11.2, C12.2, C13.2, C14.2, C15.2, C16.2, C17.2, C18.2, C19.1, C101.1, CBP1.2, FLASH1.4 (GND), FLASH1.9 (EP), GP23_LED1.1 (K), GPIO25_LED1.1 (K), J1.A1 (GND), J1.A12 (GND), J1.B1 (GND), J1.B12 (GND), J2.1, J3.3, J3.8, J3.13, J3.18, J4.3, J4.13, J4.18, J5.2, NT1.1, R5.1, R6.1, R102.2, R103.2, RSW1.1, U1.2 (GND), U2.2 (GND), U3.47 (VREG_PGND), U3.61 (GND), Y1.2, Y1.4
unnamed: C19.2, R11.2, Y1.3
unnamed: F1.1, FB1.1
unnamed: GP23_LED1.2 (A), GPIO24_RESISTOR1.1
unnamed: GPIO25_LED1.2 (A), GPIO25_RESISTOR1.1
unnamed: J1.A5 (CC1), R5.2
unnamed: J1.B5 (CC2), R6.2
unnamed: C101.2, J1.S1 (SHIELD), R102.1
unnamed: GPIO24_RESISTOR1.2, Q1.3 (D)
unnamed: CBP1.1, U1.4 (BP)
unnamed: C1.1, FB1.2, U1.1 (IN)
unnamed: R4.1, U3.51 (USB_DM)
unnamed: R3.1, U3.52 (USB_DP)
unnamed: L1.2, U3.48 (VREG_LX)
USB_D+: J1.A6 (D+), J1.B6 (D+), R3.2, TP1.1, U2.3 (I/O2), U2.4 (I/O2)
USB_D-: J1.A7 (D-), J1.B7 (D-), R4.2, TP2.1, U2.1 (I/O1), U2.6 (I/O1)
VBUS: D1.2 (A), J1.A4 (VBUS), J1.A9 (VBUS), J1.B4 (VBUS), J1.B9 (VBUS), J4.1, R101.1, U2.5 (VBUS)
VSYS: D1.1 (K), F1.2, J4.2, R7.2
XIN: C2.2, U3.21 (XIN), Y1.1
XOUT: R11.1, U3.22 (XOUT)

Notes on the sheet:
Power LED is on by default but when GPIO23 is enabled it will be shut off
GPIOs
USB/POWER
Flash
not 22pf but pick to match crystal.
Test points
LEDs
Crystal

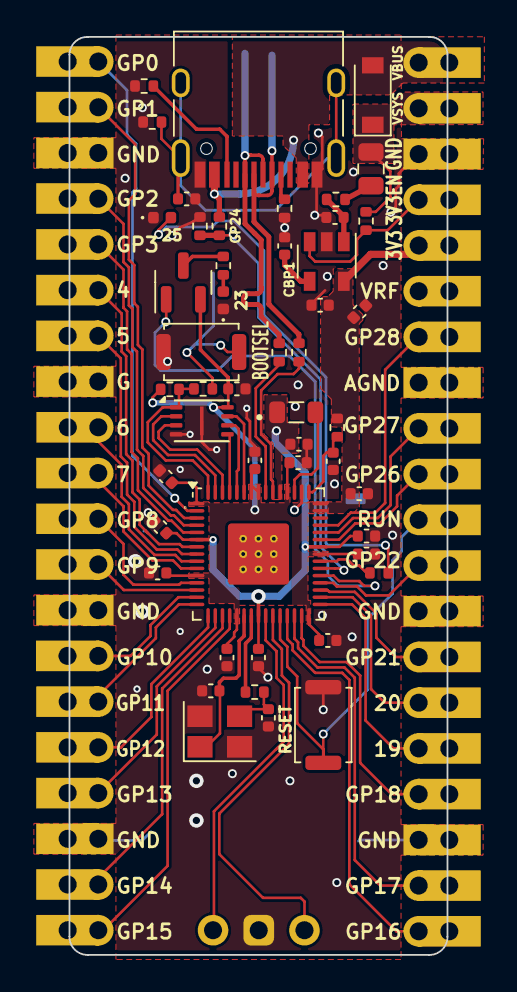
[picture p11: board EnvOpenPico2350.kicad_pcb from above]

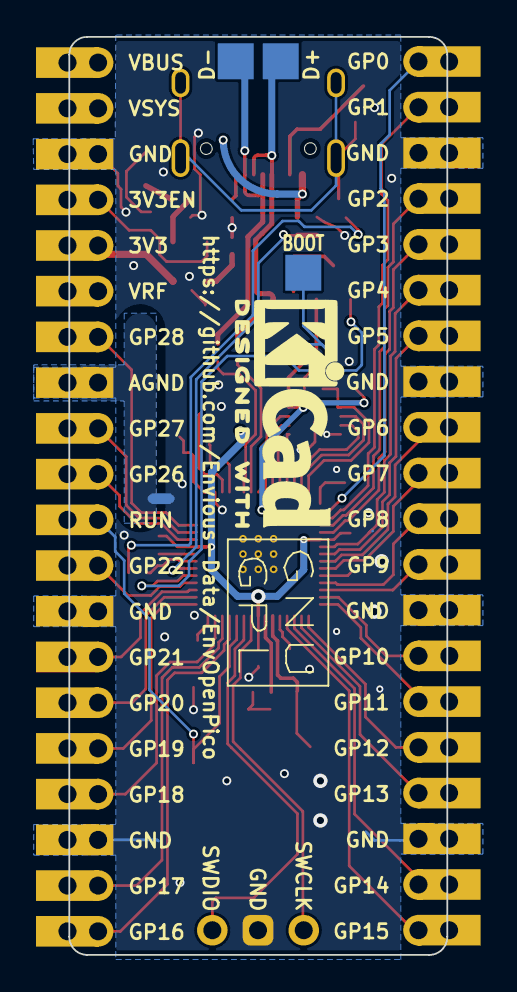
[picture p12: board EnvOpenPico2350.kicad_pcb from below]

Board: 2 copper layers, 21.0 x 51.0 mm, 56 parts (6 on the bottom side), 64 nets.

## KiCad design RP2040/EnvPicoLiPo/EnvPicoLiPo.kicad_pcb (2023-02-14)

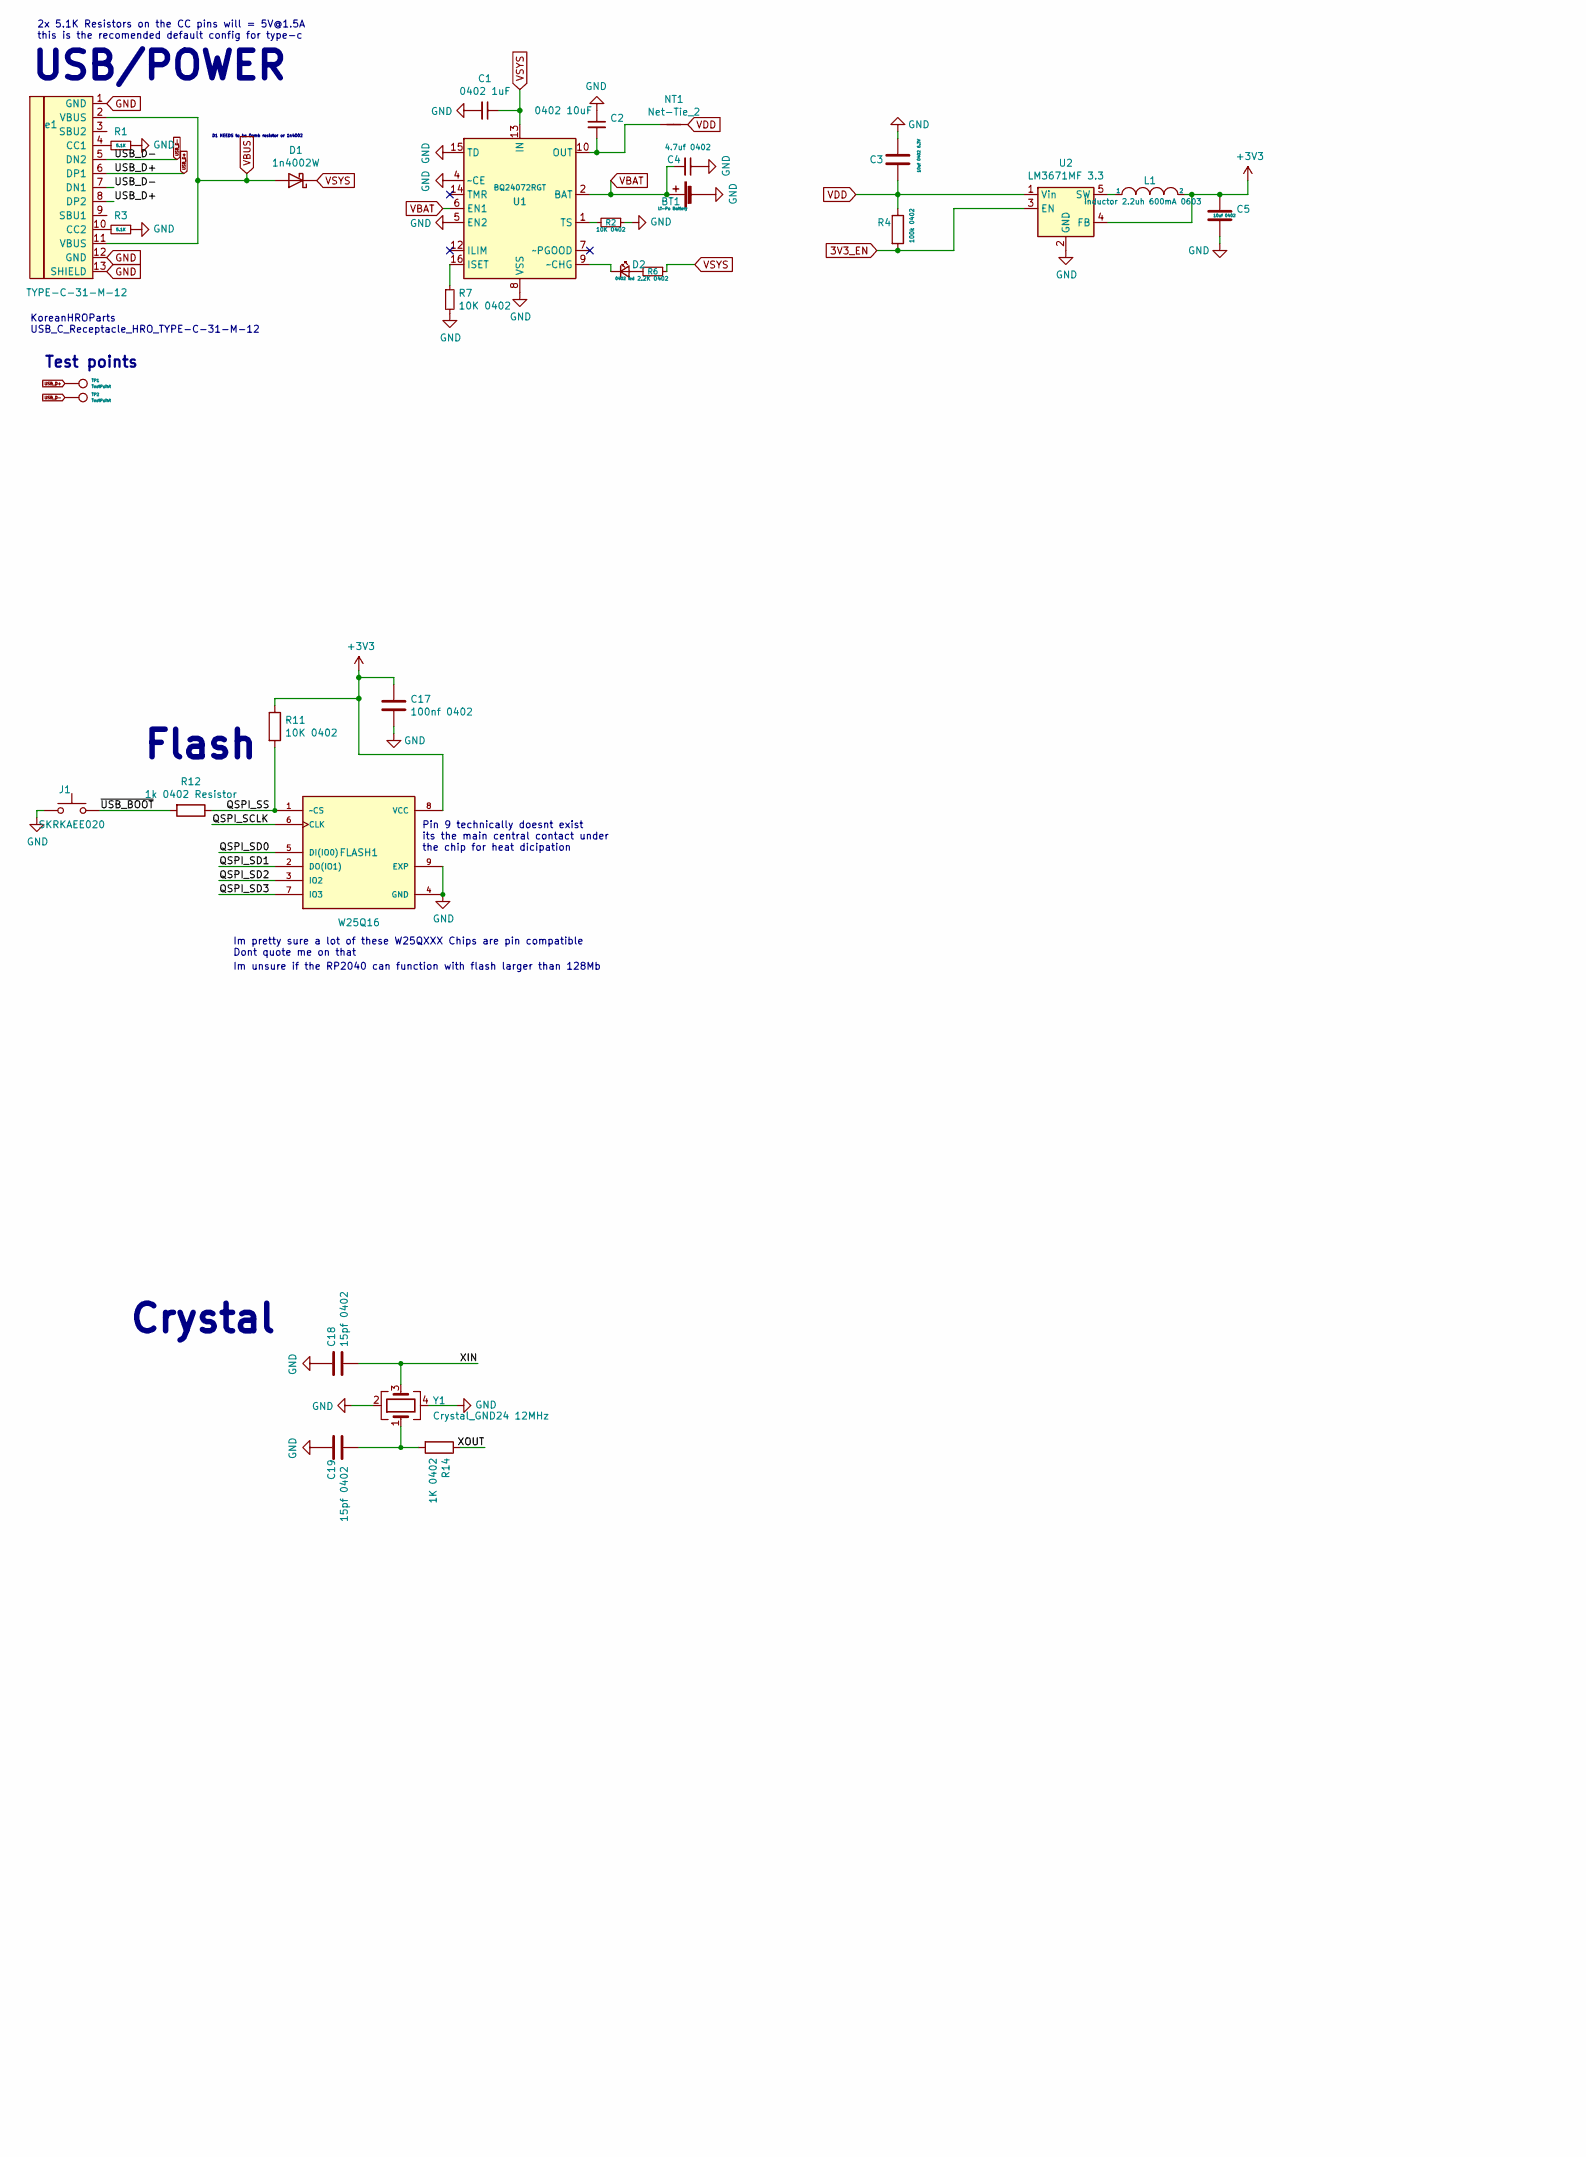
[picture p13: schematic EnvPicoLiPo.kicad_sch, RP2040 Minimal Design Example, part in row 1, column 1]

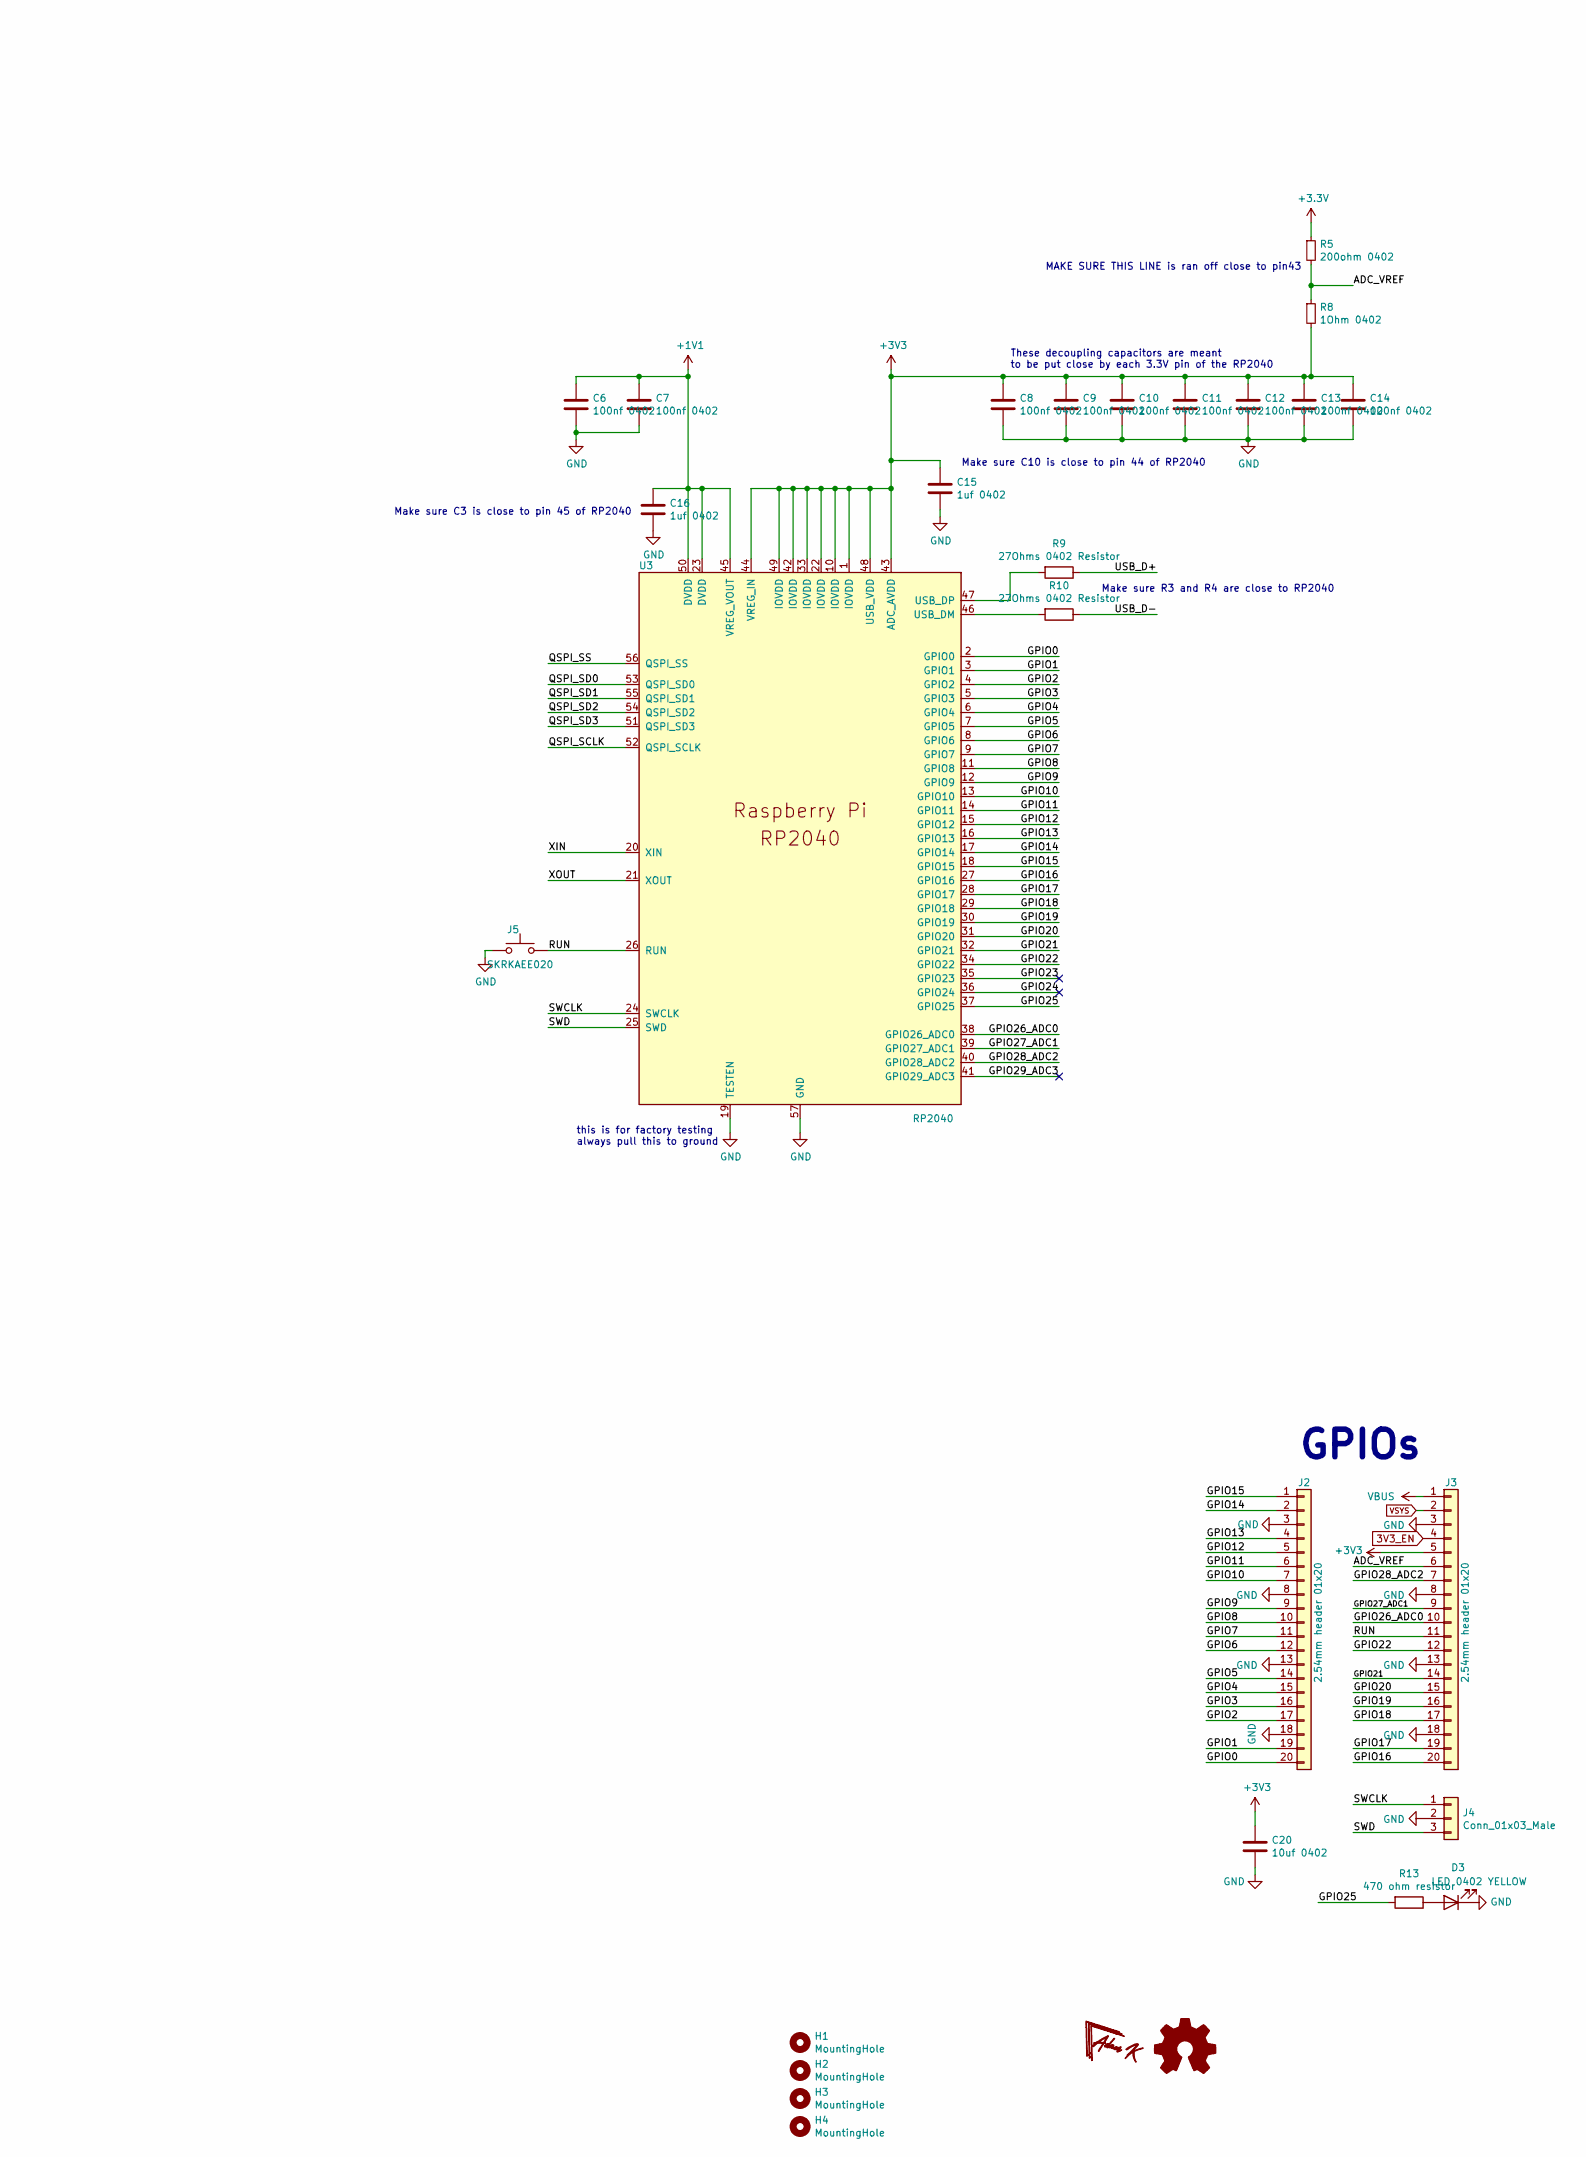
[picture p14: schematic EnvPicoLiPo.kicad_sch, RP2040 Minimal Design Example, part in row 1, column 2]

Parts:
BT1: Li-Po Battery; JST_XH_B2B-XH-A_1x02_P2.50mm_Vertical
C1: 0402 1uF; C_0402_1005Metric
C2: 0402 10uF; R_0402_1005Metric
C3: 10uf 0402 6.3V; C_0402_1005Metric
C4: 4.7uf 0402; C_0402_1005Metric
C5, C20: 10uf 0402; C_0402_1005Metric
C6, C7, C8, C9, C10, C11, C12, C13, C14, C17: 100nf 0402; C_0402_1005Metric
C15, C16: 1uf 0402; C_0402_1005Metric
C18, C19: 15pf 0402; C_0402_1005Metric
D1: 1n4002W; D_SOD-123
D2: 0402 led; LED_0402_1005Metric
D3: LED 0402 YELLOW; LED_0402_1005Metric
FLASH1: W25Q16; SON-8-1EP_3x2mm_P0.5mm_EP1.4x1.6mm
H1, H2, H3, H4: MountingHole; MountingHole_2.2mm_M2
J1, J5: SKRKAEE020; SW_Push_SPST_NO_Alps_SKRK
J2, J3: 2.54mm header 01x20; PinHeader_1x20_P2.54mm_Vertical
J4: Conn_01x03_Male; PinHeader_1x03_P2.54mm_Vertical
L1: inductor 2.2uh 600mA 0603; L_0603_1608Metric
NT1: Net-Tie_2; NetTie-2_SMD_Pad0.5mm
R1, R3: 5.1K; R_0402_1005Metric
R2, R7: 10K 0402; R_0402_1005Metric
R4: 100k 0402; R_0402_1005Metric
R5: 200ohm 0402; R_0402_1005Metric
R6: 2.2K 0402; R_0402_1005Metric
R8: 1Ohm 0402; R_0402_1005Metric
R9, R10: 27Ohms 0402 Resistor; C_0402_1005Metric
R11: 10K 0402; C_0402_1005Metric
R12: 1k 0402 Resistor; C_0402_1005Metric
R13: 470 ohm resistor; R_0402_1005Metric
R14: 1K 0402; C_0402_1005Metric
TP1, TP2: TestPoint; TestPoint_Pad_D1.0mm
U1: BQ24072RGT; VQFN-16-1EP_3x3mm_P0.5mm_EP1.6x1.6mm
U2: LM3671MF 3.3; TSOT-23-5
U3: RP2040; RP2040-QFN-56
Y1: Crystal_GND24 12MHz; Crystal_SMD_3225-4Pin_3.2x2.5mm
e1: TYPE-C-31-M-12; HRO-TYPE-C-31-M-12

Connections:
3V3_EN: J3.4, R4.2, U2.3 (EN)
+1V1: C6.1, C7.1, C16.1, U3.23 (DVDD), U3.45 (VREG_VOUT), U3.50 (DVDD)
/ADC_VREF: J3.6, R5.2, R8.1
/GPIO0: J2.20, U3.2 (GPIO0)
/GPIO1: J2.19, U3.3 (GPIO1)
/GPIO2: J2.17, U3.4 (GPIO2)
/GPIO3: J2.16, U3.5 (GPIO3)
/GPIO4: J2.15, U3.6 (GPIO4)
/GPIO5: J2.14, U3.7 (GPIO5)
/GPIO6: J2.12, U3.8 (GPIO6)
/GPIO7: J2.11, U3.9 (GPIO7)
/GPIO8: J2.10, U3.11 (GPIO8)
/GPIO9: J2.9, U3.12 (GPIO9)
/GPIO10: J2.7, U3.13 (GPIO10)
/GPIO11: J2.6, U3.14 (GPIO11)
/GPIO12: J2.5, U3.15 (GPIO12)
/GPIO13: J2.4, U3.16 (GPIO13)
/GPIO14: J2.2, U3.17 (GPIO14)
/GPIO15: J2.1, U3.18 (GPIO15)
/GPIO16: J3.20, U3.27 (GPIO16)
/GPIO17: J3.19, U3.28 (GPIO17)
/GPIO18: J3.17, U3.29 (GPIO18)
/GPIO19: J3.16, U3.30 (GPIO19)
/GPIO20: J3.15, U3.31 (GPIO20)
/GPIO21: J3.14, U3.32 (GPIO21)
/GPIO22: J3.12, U3.34 (GPIO22)
/GPIO23: U3.35 (GPIO23)
/GPIO24: U3.36 (GPIO24)
/GPIO25: R13.2, U3.37 (GPIO25)
/GPIO26_ADC0: J3.10, U3.38 (GPIO26_ADC0)
/GPIO27_ADC1: J3.9, U3.39 (GPIO27_ADC1)
/GPIO28_ADC2: J3.7, U3.40 (GPIO28_ADC2)
/GPIO29_ADC3: U3.41 (GPIO29_ADC3)
/QSPI_SCLK: FLASH1.6 (CLK), U3.52 (QSPI_SCLK)
/QSPI_SD0: FLASH1.5 (DI(IO0)), U3.53 (QSPI_SD0)
/QSPI_SD1: FLASH1.2 (DO(IO1)), U3.55 (QSPI_SD1)
/QSPI_SD2: FLASH1.3 (IO2), U3.54 (QSPI_SD2)
/QSPI_SD3: FLASH1.7 (IO3), U3.51 (QSPI_SD3)
/QSPI_SS: FLASH1.1 (~CS), R11.2, R12.1, U3.56 (QSPI_SS)
/RUN: J3.11, J5.1, U3.26 (RUN)
/SWCLK: J4.1, U3.24 (SWCLK)
/SWD: J4.3, U3.25 (SWD)
/XIN: C18.2, U3.20 (XIN), Y1.3
/XOUT: R14.1, U3.21 (XOUT)
/~USB_BOOT: J1.1, R12.2
GND: BT1.2 (-), C1.2, C2.1, C3.2, C4.1, C5.2, C6.2, C7.2, C8.2, C9.2, C10.2, C11.2, C12.2, C13.2, C14.2, C15.2, C16.2, C17.2, C18.1, C19.1, C20.2, D3.1 (K), FLASH1.4 (GND), FLASH1.9 (EXP), J1.2, J2.3, J2.8, J2.13, J2.18, J3.3, J3.8, J3.13, J3.18, J4.2, J5.2, R1.1, R2.1, R3.1, R7.2, U1.4 (~CE), U1.5 (EN2), U1.8 (VSS), U1.15 (TD), U1.17 (VSS), U2.2 (GND), U3.19 (TESTEN), U3.57 (GND), Y1.2, Y1.4, e1.1 (GND), e1.12 (GND), e1.13 (SHIELD)
unnamed: C2.2, NT1.1, U1.10 (OUT), U1.11 (OUT)
unnamed: C19.2, R14.2, Y1.1
unnamed: D2.2 (A), R6.2
unnamed: D2.1 (K), U1.9 (~CHG)
unnamed: D3.2 (A), R13.1
unnamed: R7.1, U1.16 (ISET)
unnamed: R2.2, U1.1 (TS)
unnamed: L1.1, U2.5 (SW)
unnamed: R10.2, U3.46 (USB_DM)
unnamed: R9.2, U3.47 (USB_DP)
unnamed: R1.2, e1.4 (CC1)
unnamed: R3.2, e1.10 (CC2)
USB_D+: R9.1, TP1.1, e1.6 (DP1), e1.8 (DP2)
USB_D-: R10.1, TP2.1, e1.5 (DN2), e1.7 (DN1)
VBAT: BT1.1 (+), C4.2, U1.2 (BAT), U1.3 (BAT), U1.6 (EN1)
VBUS: D1.2 (A), J3.1, e1.2 (VBUS), e1.11 (VBUS)
VDD: C3.1, NT1.2, R4.1, U2.1 (Vin)
VSYS: C1.1, D1.1 (K), J3.2, R6.1, U1.13 (IN)

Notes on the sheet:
Test points
D1 NEEDS to be 0omh resistor or 1n4002
Crystal
Flash
These decoupling capacitors are meant to be put close by each 3.3V pin of the RP2040
USB/POWER
Make sure R3 and R4 are close to RP2040
Im unsure if the RP2040 can function with flash larger than 128Mb
2x 5.1K Resistors on the CC pins will = 5V@1.5A this is the recomended default config for type-c
GPIOs
Make sure C10 is close to pin 44 of RP2040
KoreanHROParts USB_C_Receptacle_HRO_TYPE-C-31-M-12
Pin 9 technically doesnt exist its the main central contact under the chip for heat dicipation
Make sure C3 is close to pin 45 of RP2040
Im pretty sure a lot of these W25QXXX Chips are pin compatible Dont quote me on that
this is for factory testing always pull this to ground
MAKE SURE THIS LINE is ran off close to pin43

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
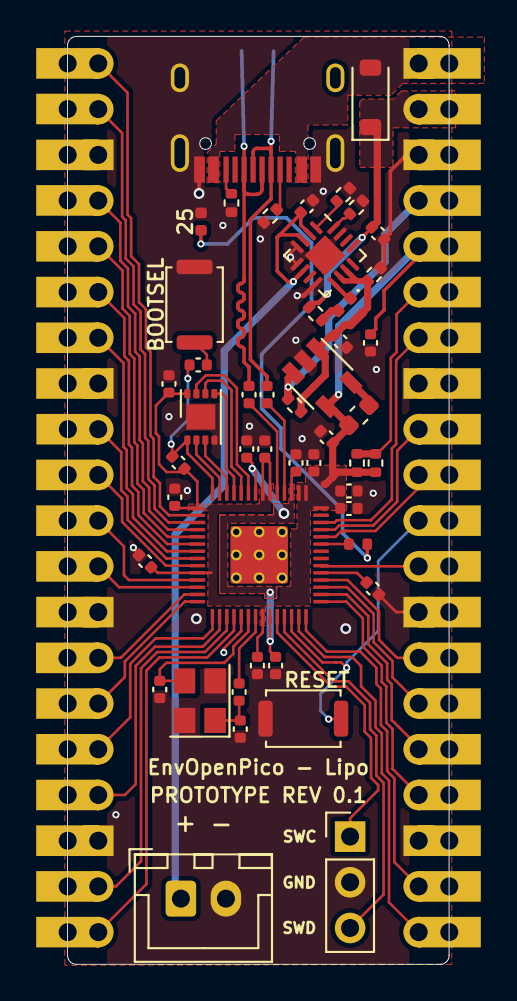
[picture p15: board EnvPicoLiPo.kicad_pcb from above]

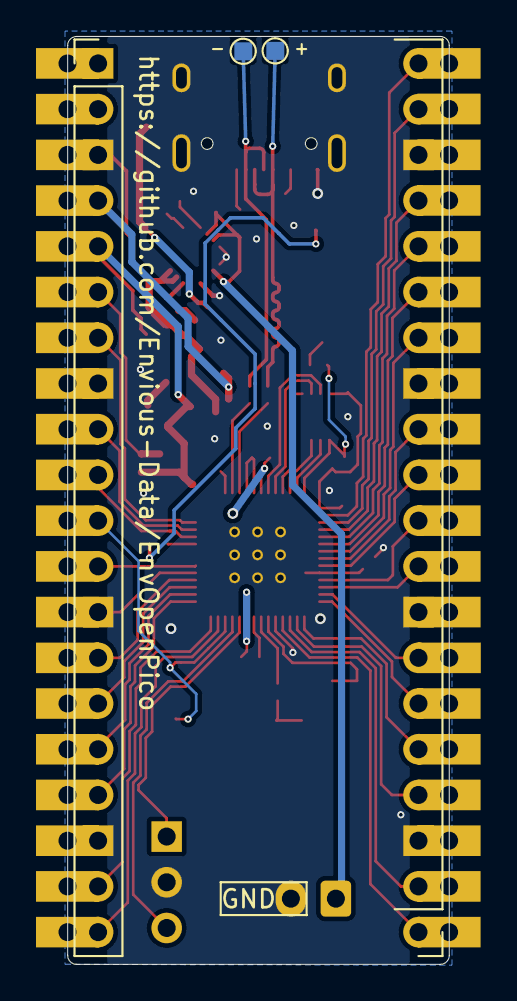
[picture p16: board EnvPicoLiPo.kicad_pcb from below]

Board: 2 copper layers, 21.2 x 51.6 mm, 57 parts (4 on the bottom side), 62 nets.

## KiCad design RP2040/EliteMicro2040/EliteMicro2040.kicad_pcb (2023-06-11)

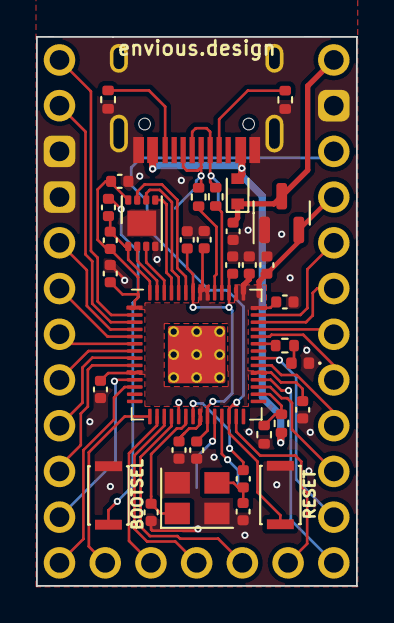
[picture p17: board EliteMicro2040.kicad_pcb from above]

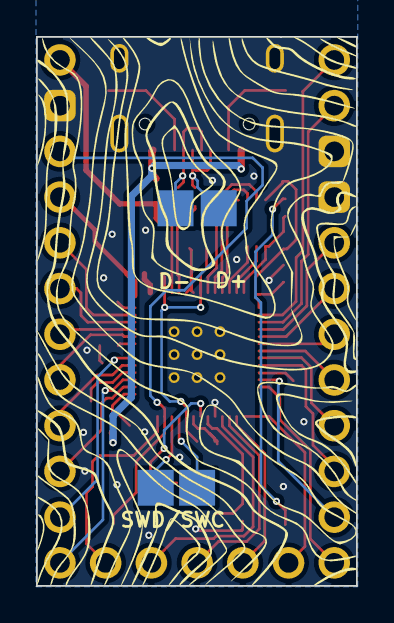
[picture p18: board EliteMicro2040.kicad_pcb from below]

Board: 2 copper layers, 17.8 x 30.5 mm, 39 parts (4 on the bottom side), 50 nets.

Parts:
C1, C3, C4, C10: 1uf 0201; C_0402_1005Metric
C2: 22pF 0402; C_0402_1005Metric
C5, C6, C7, C8, C11, C13, C14, C15, C18: 100nf 0201; C_0402_1005Metric
C19: 22pf 0402; C_0402_1005Metric
D1: SOD-523 General; D_SOD-523
FLASH1: W25Q16JVUXIQ; SON-8-1EP_3x2mm_P0.5mm_EP1.4x1.6mm
GPIO25_LED1: LED 0201; LED_0402_1005Metric
GPIO25_RESISTOR1: 1K 0201; R_0402_1005Metric
J1, J2: Button; SW_SPST_CK_KXT3
R1, R7: 1K 0201; C_0402_1005Metric
R2: 10K 0201; C_0402_1005Metric
R3, R4: 27r 0201; R_0402_1005Metric
R5, R6: 5.1K 0201; R_0402_1005Metric
R101: 5.6k 0201; R_0402_1005Metric
R102: 10k 0201; R_0402_1005Metric
TP1, TP2, TP101, TP103: TestPoint; CustomTestPoint
U1: ZL6201A33S3; SOT-23
U2: Elite-C
U3: RP2040; RP2040-QFN-56
USB2: HRO-TYPE-C-31-M-12
Y1: 3225-4P 12MHz; Crystal_SMD_3225-4Pin_3.2x2.5mm

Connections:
+1V1: C3.1, C6.1, C7.1, U3.23 (DVDD), U3.45 (VREG_VOUT), U3.50 (DVDD)
+3V3: C4.1, C5.1, C8.1, C10.1, C11.1, C13.1, C14.1, C15.1, C18.1, FLASH1.8 (VCC), R2.1, U1.2 (VO), U2.21 (VCC), U3.1 (IOVDD), U3.10 (IOVDD), U3.22 (IOVDD), U3.33 (IOVDD), U3.42 (IOVDD), U3.43 (ADC_AVDD), U3.44 (VREG_IN), U3.48 (USB_VDD), U3.49 (IOVDD)
/GPIO0: U2.1 (TX0/PD3), U3.2 (GPIO0)
/GPIO1: U2.2 (RX1/PD2), U3.3 (GPIO1)
/GPIO2: U2.5 (2/PD1), U3.4 (GPIO2)
/GPIO3: U2.6 (3/PD0), U3.5 (GPIO3)
/GPIO4: U2.7 (4/PD4), U3.6 (GPIO4)
/GPIO5: U2.8 (5/PC6), U3.7 (GPIO5)
/GPIO6: U2.9 (6/PD7), U3.8 (GPIO6)
/GPIO7: U2.10 (7/PE6), U3.9 (GPIO7)
/GPIO8: U2.11 (8/PB4), U3.11 (GPIO8)
/GPIO9: U2.12 (9/PB5), U3.12 (GPIO9)
/GPIO12: U2.25 (B7), U3.15 (GPIO12)
/GPIO13: U2.26 (D5), U3.16 (GPIO13)
/GPIO14: U2.27 (C7), U3.17 (GPIO14)
/GPIO15: U2.28 (F1), U3.18 (GPIO15)
/GPIO16: U2.29 (F0), U3.27 (GPIO16)
/GPIO19: R101.2, R102.1, U3.30 (GPIO19)
/GPIO20: U2.15 (14/PB3), U3.31 (GPIO20)
/GPIO21: U2.13 (10/PB6), U3.32 (GPIO21)
/GPIO22: U2.16 (15/PB1), U3.34 (GPIO22)
/GPIO23: U2.14 (16/PB2), U3.35 (GPIO23)
/GPIO25: GPIO25_RESISTOR1.2, U3.37 (GPIO25)
/GPIO26_ADC0: U2.17 (A0/PF7), U3.38 (GPIO26_ADC0)
/GPIO27_ADC1: U2.18 (A1/PF6), U3.39 (GPIO27_ADC1)
/GPIO28_ADC2: U2.19 (A2/PF5), U3.40 (GPIO28_ADC2)
/GPIO29_ADC3: U2.20 (A3/PF4), U3.41 (GPIO29_ADC3)
/QSPI_SCLK: FLASH1.6 (CLK), U3.52 (QSPI_SCLK)
/QSPI_SD0: FLASH1.5 (DI(IO0)), U3.53 (QSPI_SD0)
/QSPI_SD1: FLASH1.2 (DO(IO1)), U3.55 (QSPI_SD1)
/QSPI_SD2: FLASH1.3 (IO2), U3.54 (QSPI_SD2)
/QSPI_SD3: FLASH1.7 (IO3), U3.51 (QSPI_SD3)
/QSPI_SS: FLASH1.1 (~CS), R1.1, R2.2, U3.56 (QSPI_SS)
/RUN: J1.1, U2.22 (RST), U3.26 (RUN)
/SWCLK: TP101.1, U3.24 (SWCLK)
/SWD: TP103.1, U3.25 (SWD)
/~USB_BOOT: J2.1, R1.2
GND: C1.2, C2.2, C3.2, C4.2, C5.2, C6.2, C7.2, C8.2, C10.2, C11.2, C13.2, C14.2, C15.2, C18.2, C19.2, FLASH1.4 (GND), FLASH1.9 (EP), GPIO25_LED1.1 (K), J1.2, J2.2, R5.1, R6.1, R102.2, U1.1 (GND), U2.3 (GND), U2.4 (GND), U2.23 (GND), U3.19 (TESTEN), U3.57 (GND), USB2.1 (GND), USB2.12 (GND), USB2.13 (SHIELD), Y1.2, Y1.4
unnamed: C2.1, R7.1, Y1.3
unnamed: GPIO25_LED1.2 (A), GPIO25_RESISTOR1.1
unnamed: R4.2, U3.46 (USB_DM)
unnamed: R3.2, U3.47 (USB_DP)
unnamed: C19.1, U3.20 (XIN), Y1.1
unnamed: R7.2, U3.21 (XOUT)
unnamed: R5.2, USB2.4 (CC1)
unnamed: R6.2, USB2.10 (CC2)
USB_D+: R3.1, TP1.1, USB2.6 (DP1), USB2.8 (DP2)
USB_D-: R4.1, TP2.1, USB2.5 (DN2), USB2.7 (DN1)
VBUS: D1.2 (A), R101.1, USB2.2 (VBUS), USB2.11 (VBUS)
VSYS: C1.1, D1.1 (K), U1.3 (VI), U2.24 (B0)

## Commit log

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2021-04-27 Redesign
    I need sleep.
    [EnvOpenPico.kicad_pcb, EnvOpenPico.sch]
2021-04-27 Swapped Crystal for smaller XO oscillator
    + some general other changes
    [EnvOpenPico.kicad_pcb, EnvOpenPico.sch]
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2021-04-28 Replaced MicroB with Type-C
    [EnvOpenPico.kicad_pcb, EnvOpenPico.sch]
2021-04-28 I forgot what I went to adjust but I did something or another.
    [EnvOpenPico.kicad_pcb]
2021-04-28 replaced the 3.3V out diode for a smaller one
    [EnvOpenPico.kicad_pcb, EnvOpenPico.sch]
2021-04-28 Made the board 0.09mm wider and adjusted the ground planes
    [EnvOpenPico.kicad_pcb]
2021-04-28 Moved some vias to account for mechanical damage
    [EnvOpenPico.kicad_pcb]
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2021-04-29 Changed Regulator for one with an enable pin
    [EnvOpenPico.kicad_pcb, EnvOpenPico.sch]
2021-04-30 Changed SOIC Flash for WSON Flash
    also added a button instead of 1mm pitch headers along with general other track adjustments and stuff.
    [EnvOpenPico.kicad_pcb, EnvOpenPico.sch]
2021-05-01 Updated some components to be JLCPCB SMT Assembly compatible
    [EnvOpenPico.kicad_pcb, EnvOpenPico.sch]
2021-05-01 Added a Bunch of notes and useful info to the schematic
    [EnvOpenPico.sch]
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2021-05-03 Changed flash part number for a compatible version incase JLC has stock
    [EnvOpenPico.sch]
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2021-05-05 some silkscreen adjustments and a couple added notes to schematic
    [EnvOpenPico.kicad_pcb, EnvOpenPico.sch]
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2021-05-14 Corrected some notes
    [EnvOpenPico.sch, _bomfile.csv, _posfile.csv]
2021-05-14 Adjusted lables and notes some more for BOM export
    [EnvOpenPico.sch]
2021-05-15 some more adjustments to correct auto filling fields in JLCPCB
    [EnvOpenPico-B_CrtYd.gbr, EnvOpenPico-B_Cu.gbl, EnvOpenPico-B_Fab.gbr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]
2021-05-20 Replaced Flash footprint with USON-8/3x2mm to match received samples
    [EnvOpenPico.kicad_pcb, EnvOpenPico.sch]
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2021-06-07 unsure if permanent but can get a hold of components RPI Pico uses
    [EnvOpenPico-B_Cu.gbl, EnvOpenPico-B_Mask.gbs, EnvOpenPico-B_Paste.gbp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]
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2021-06-12 Changed out some parts and added more details to their BOM comments
    [EnvOpenPico-B_Cu.gbl, EnvOpenPico-B_Mask.gbs, EnvOpenPico-B_Paste.gbp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]
2021-06-26 Swapped RT6150GQW for TPS63002
    [EnvOpenPico.kicad_pcb, EnvOpenPico.sch]
2021-06-28 Swapped flash chip for larger version, JLCPCB now stocks the RP2040
    [EnvOpenPico.kicad_pcb, EnvOpenPico.sch]
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2021-07-23 Corrected some library bits.
    [EnvOpenPico.kicad_pcb]
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2021-07-26 small corrections and added a couple test points.
    [EnvOpenPico.kicad_pcb, EnvOpenPico.sch]
2021-07-26 Rotated Oscillator by 180 degrees
    [EnvOpenPico.kicad_pcb]
2021-07-26 corrected reveresed usb debug pads, added gnd debug pad and incremented revision number.
    [EnvOpenPico.kicad_pcb, EnvOpenPico.sch]
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2021-07-27 moved some components to better locations and also created more filled areas
    [EnvOpenPico.kicad_pcb]
2021-07-29 Hopefully implemented ADC_VREF Correctly on dip40 and pico verrsion
    [Dip40-RP2040.kicad_pcb, Dip40-RP2040.sch, EnvOpenPico.kicad_pcb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]
2021-07-29 updated readme and corrected a capacitor placement.
    [EnvOpenPico.kicad_pcb, EnvOpenPico.sch]
2021-07-31 corrected capacitor placement.
    [Dip40-RP2040.kicad_pcb]
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2021-07-31 bit of a redesign.
    [EnvOpenPico.kicad_pcb, EnvOpenPico.sch]
2021-07-31 added some extra notes and moved some parts about, added some test points.
    [EnvOpenPico.kicad_pcb, EnvOpenPico.sch]
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2021-08-13 started work on a RP2040 board with a ESP BT/WIFI slave and a battery charge/management IC
    [EnvPicoLiPo.kicad_pcb, EnvPicoLiPo.sch]
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2021-08-14 added some silkscreen pin lables where possible on the front (they'll be on the back otherwise.)
    [EnvOpenPico.kicad_pcb]
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2021-08-14 Corrected all the via placements so they dont cause issues and removed some redundant parts
    [EnvPicoLiPo.kicad_pcb, EnvPicoLiPo.kicad_sch, EnvPicoLiPo.sch]
2021-08-14 corrected via sizes and placements.
    [EnvOpenPico.kicad_pcb]
2021-08-15 replaced XO with crystal due to stock issues, and some general cleanups and corrections
    [EnvOpenPico.kicad_pcb, EnvOpenPico.sch]
2021-08-18 added keepout zones around the pins to avoid shorts
    [EnvOpenPico.kicad_pcb, EnvOpenPico.sch]
2021-08-18 woops made sure keepout zone was on both sides of the pcb.
    [EnvOpenPico.kicad_pcb]
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2021-08-23 removed ESP32 and wifi bits for now, will re-add something later on with further testing.
    [EnvPicoLiPo.kicad_pcb, EnvPicoLiPo.kicad_sch]
2021-08-23 cleanup + sorted out some spacing and trace misalignment.
    [EnvOpenPico-B_Cu.gbl, EnvOpenPico-B_Mask.gbs, EnvOpenPico-B_Paste.gbp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]
2021-08-23 moved the battery connector to the bottom of the board and rotated the debug header 90 degrees to fit along side.
    [EnvPicoLiPo.kicad_pcb, EnvPicoLiPo.kicad_sch]
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2021-08-25 Swapped TPS6300x for TLV75533PDBVR due to stock issues.
    [EnvOpenPico-B_Cu.gbl, EnvOpenPico-B_Mask.gbs, EnvOpenPico-B_Paste.gbp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]
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2021-08-26 added a optinal bypass resistor cBP1 incase an alternative SOT-23-5 regulator is installed. + moved more pinout silkscreen to the front.
    [EnvOpenPico.kicad_pcb, EnvOpenPico.sch]
2021-08-26 small adjustment to a few tracks and vias to allow for more ground plane coverage.
    [EnvOpenPico.kicad_pcb]
2021-09-04 generated upto date Gerber (also made sure csv files are uploaded to github)
    [EnvOpenPico.kicad_pcb, EnvOpenPico_bom_jlc.csv, EnvPicoLiPo.csv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]
2021-09-04 made some silkscreen more readable and moved TP pads for USB closer to where they are on the RPI Pico.
    [EnvOpenPico.kicad_pcb]
2021-09-09 Added a small note on a stocked Flash IC that JLC has loads of (as of right now.)
    [EnvOpenPico.sch]
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2021-09-11 Swapped type-c port footprint for hand solder version.
    [EnvOpenPico.kicad_pcb, EnvOpenPico.sch, EnvOpenPico_bom_jlc.csv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]
2021-09-11 added a resistor that I missed and once again generated updated gerbers lol.
    [EnvOpenPico.kicad_pcb, EnvOpenPico.sch, EnvOpenPico_bom_jlc.csv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]
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2021-09-14 Generated updated gerbers, replaced type-c HS with ASM.
    [EnvOpenPico.kicad_pcb, EnvOpenPico_bom_jlc.csv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]
2021-09-14 corrected footprints for R3 and R4 in the schematic
    [EnvOpenPico.kicad_pcb, EnvOpenPico.sch, EnvOpenPico_bom_jlc.csv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]
2021-09-14 Added then removed agnd, fixed pin header row silkscreen and removed R3/R4 silkscreen ref
    [EnvOpenPico.kicad_pcb, EnvOpenPico.sch]
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2021-09-14 Generated Fixed Gerber.
    There was an odd issue where if the reference wasn't ALL CAPS it didn't show up in the parts list.
    [EnvOpenPico-B_CrtYd.gbr, EnvOpenPico-B_Cu.gbl, EnvOpenPico-B_Fab.gbr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]
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2021-09-14 swapped LEDs for 0603 size due to better avaliability.
    [EnvOpenPico-B_CrtYd.gbr, EnvOpenPico-B_Cu.gbl, EnvOpenPico-B_Fab.gbr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]
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2021-10-28 corrected some things, it appears GD25Q40 doesnt work with the RP2040 but the GD25Q16/32/64 work fine.
    [EnvOpenPico.kicad_pcb, EnvOpenPico.sch]
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2021-10-28 changed JST connector for more common type, adjusted some parts to do with flash
    [EnvPicoLiPo.kicad_pcb, EnvPicoLiPo.kicad_sch]
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2021-11-06 corrected library symbol for reset button
    [EnvOpenPico.kicad_pcb, EnvOpenPico.sch]
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2021-11-17 Corrected a small bug in the gerber.
    [EnvOpenPico-B_Cu.gbl, EnvOpenPico-B_Fab.gbr, EnvOpenPico-B_Mask.gbs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]
2021-11-21 Generated updated gerber and fixed 2 random issues as per DRC
    [EnvOpenPico.kicad_pcb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]
2021-11-25 Created Keyboard specific version that has a JST connector compatible with the unified daughterboard by ai03-2727
    [EnvPicoKB.kicad_pcb, EnvPicoKB.sch]
2021-11-26 woops, wrong JST connector lol.
    [EnvPicoKB.kicad_pcb, EnvPicoKB.sch]
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2021-12-09 shortened pcb, added bypass resistor, pads for SPI flash and supporting decoupling capacitor
    [EliteMicro2040.kicad_pcb, EliteMicro2040.sch]
2021-12-17 swapped various parts to 0201 and added fuse between VSYS and linear reg
    [EnvOpenPico.kicad_pcb, EnvOpenPico.sch]
2021-12-25 corrected a placeholder reference I forgot to label as such, also added more comments in the schematic for the main design.
    [EnvOpenPico.sch, EnvPicoKB.sch]
2021-12-27 removed Dip40 versions, changed fuse on main version to 805 size and added part number.
    [Dip40-RP2040-32A.kicad_pcb, Dip40-RP2040-32A.sch, Dip40-RP2040.kicad_pcb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]
2022-01-11 Lots of changes, redid elite-c version, added more debug pads to main version and various tweaks among other things.
    [EliteMicro2040.kicad_pcb, EliteMicro2040.sch, EnvOpenPico.kicad_pcb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]
2022-01-11 Swapped regulator for a smaller one, need to re-arrange some bits it seems.
    [EliteMicro2040.kicad_pcb, EliteMicro2040.sch]
2022-01-15 Added extra SPI Flash, swapped regulator due to stock issues, updated git ignore.
    [EliteMicro2040.kicad_pcb, EliteMicro2040.kicad_sch]
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2022-01-24 Added 0402 ferrite for noise suppression and added a seperate ground plane under the Analogue pins.
    Analogue stuff is basically voodoo it seems.
    [EnvOpenPico.kicad_pcb, EnvOpenPico.kicad_sch]
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2022-03-07 swapped out a 10K 0201 for a 10K 0402
    [EnvOpenPico.kicad_pcb, EnvOpenPico.kicad_sch]
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2022-04-27 swapped some parts back to 0402 size due to stock issues among fixes.
    [EnvOpenPico.kicad_pcb, EnvOpenPico.kicad_sch]
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2022-05-21 some silkscreen fixes and generated updated gerber/cpl/bom
    [EnvOpenPico.kicad_pcb, EnvOpenPico_bom_jlc.csv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]
2022-05-23 removed some parts and swapped flash to soic package for stock reasons.
    [EnvOpenPico.kicad_pcb, EnvOpenPico.kicad_sch, EnvOpenPico_bom_jlc.csv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]
2022-06-04 made some changes in the schematic to conform more with the USB Spec,
    [EnvOpenPico.kicad_pcb, EnvOpenPico.kicad_sch]
2022-06-15 implemented schematic changes and replaced flash with smaller one
    [EnvOpenPico.kicad_pcb]
2022-06-16 removed KB version since its now irrelevant, Generated updated gerbers, bom and CPL as well as made chnges to the PCB based on prior schematic adjustments
    [EnvOpenPico.kicad_pcb, EnvOpenPico.sch, EnvOpenPico_bom_jlc.csv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]
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2022-06-30 modified board to fit with bastardKB's standard, added vbus sense, changed pinout, removed reset button and moved bootsel, removed SPI EEPROM as its not supported.
    [EliteMicro2040.kicad_pcb, EliteMicro2040.kicad_sch]
2022-07-01 lots of changes, swapped many parts to 0402, swapped SOT regulator to small WSON, made sure there is proper parity between footprint and value, etc etc etc
    [EliteMicro2040.kicad_pcb, EliteMicro2040.kicad_sch, EliteMicro2040_bom_jlc.csv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]
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2022-07-07 swapped flash for one that was in stock.
    [EnvOpenPico.kicad_pcb, EnvOpenPico.kicad_sch, EnvOpenPico_bom_jlc.csv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]
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2022-08-05 incr version, added mosfet and led for GP23, marked GP24, tiny bits of cleanup and DRC checks.
    [EnvOpenPico.kicad_pcb, EnvOpenPico.kicad_sch]
2022-10-06 added diode after VBUS to make sure VBUS Detect can work properly.
    [EliteMicro2040.kicad_pcb, EliteMicro2040.kicad_sch]
2022-10-14 made various improvements to design such as swapping vbus for vsys on the raw pin
    [EliteMicro2040.kicad_pcb, EliteMicro2040.kicad_sch, EliteMicro2040_bom_jlc.csv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]
2022-10-30 General re-work of board to ensure less chance of failure
    [EliteMicro2040.kicad_pcb, EliteMicro2040.kicad_sch, EliteMicro2040_bom_jlc.csv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]
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2022-11-29 small various tweaks and fixes
    [EliteMicro2040.kicad_pcb, EliteMicro2040_bom_jlc.csv]
2022-11-29 tiny fix on one of the trace widths
    [EliteMicro2040.kicad_pcb]
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2022-12-08 some small fixes regarding the silkscreen and 3d models
    [EliteMicro2040.kicad_pcb, EnvOpenPico.kicad_sch]
2022-12-08 bumped minimum clearance and trace thickness to 0.15mm and re-did all traces with less clearance or less thickness
    [EnvOpenPico.kicad_pcb]
2022-12-23 swapped regulator to sot-23-3 version
    [EliteMicro2040.kicad_pcb, EliteMicro2040.kicad_sch]
2022-12-23 swapped crystal for 3225 version
    [EliteMicro2040.kicad_pcb, EliteMicro2040.kicad_sch]
2022-12-24 missing files commit
    [EliteMicro2040.kicad_pcb]
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2023-02-13 replaced flash symbol with built in one, some clearance fixes
    [EliteMicro2040.kicad_pcb, EliteMicro2040.kicad_sch, EnvOpenPico.kicad_pcb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]
2023-02-14 overhauled battery version, not many changes other than increasing clearance across the board
    [EnvPicoLiPo.kicad_pcb]
2023-02-14 added missing bootsel silkscreen
    [EliteMicro2040.kicad_pcb]
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2023-03-04 fixed major potential oversight on 3V3_EN being tied to VBUS rather than VSYS.
    [EnvOpenPico.kicad_pcb, EnvOpenPico.kicad_sch]
2023-03-04 fixed ADC_AVDD being tied to 3V3 incorrectly, various tweaks and adjustments to part positions to ensure everything fits properly
    [EnvOpenPico.kicad_pcb, EnvOpenPico.kicad_sch]
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2023-03-06 re-aligned some parts to be properly centered, not important but wanted to do it.
    [EnvOpenPico.kicad_pcb, EnvOpenPico.kicad_sch]
2023-06-11 small fix to a couple traces
    [EliteMicro2040.kicad_pcb]
2023-06-11 Created Experimental version to fit all 0402 components and a top mount type-c port
    [EliteMicro2040.csv, EliteMicro2040.kicad_pcb, EliteMicro2040.kicad_sch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]
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2023-06-11 corrected some bits
    [EliteMicro2040.kicad_pcb]
2023-06-11 fixed up some things in the gerber, cpl and bom
    [EliteMicro2040.kicad_pcb, EliteMicro2040.kicad_sch, bom.csv]
2023-10-10 swapped the symbol and footprint for the type-c port to the kicad built in one
    [EnvOpenPico.kicad_pcb, EnvOpenPico.kicad_sch]
2024-03-27 corrected picture of lipo version (it doesnt have a wifi slave anymore)
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2024-11-03 made many corrections to RP2040 pico board, silkscreen, positioning, footprint, any errors I could find.
    [EnvOpenPico-RP2040.kicad_pcb, EnvOpenPico-RP2040.kicad_sch]
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2024-11-03 made various corrections and adjustments to the board, generated production files.
    [EnvOpenPico2350.kicad_pcb, EnvOpenPico2350.kicad_sch, bom.csv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]
